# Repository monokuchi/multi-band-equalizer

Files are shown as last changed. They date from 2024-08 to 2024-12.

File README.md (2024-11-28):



<!-- PROJECT LOGO -->
<div align="center">
  <h1>Multi-Band Equalizer</h1>
  <p>
    Multi-band parametric equalizer implemented using a STM32H7 ARM7 Microcontroller along with a Cirrus Logic CS4272-CZZ Audio Codec
  </p>
</div>

<!-- PROJECT DESCRIPTION -->
<h2>Description</h2> 

<header>
    <ul>
        <li><h3>Multi-Band-Equalizer Front Side</h3></li>
    </ul>
</header>

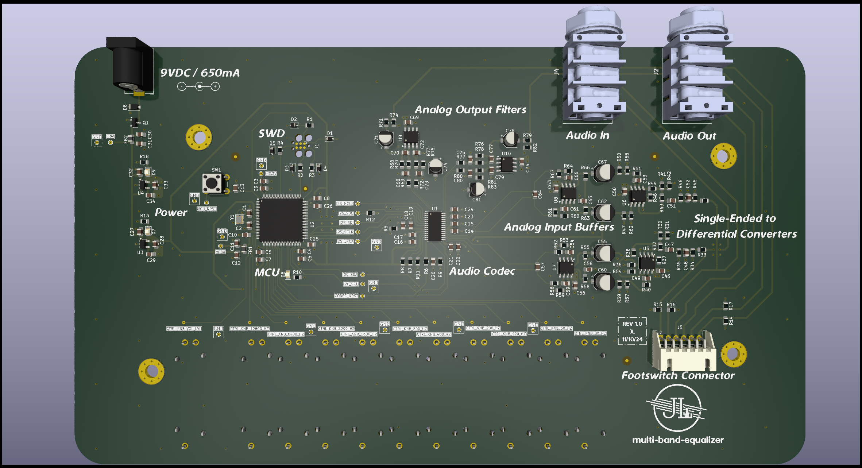
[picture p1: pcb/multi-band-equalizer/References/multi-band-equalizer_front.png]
Multi-Band-Equalizer PCB Front Side


<header>
    <ul>
        <li><h3>Multi-Band-Equalizer Back Side</h3></li>
    </ul>
</header>

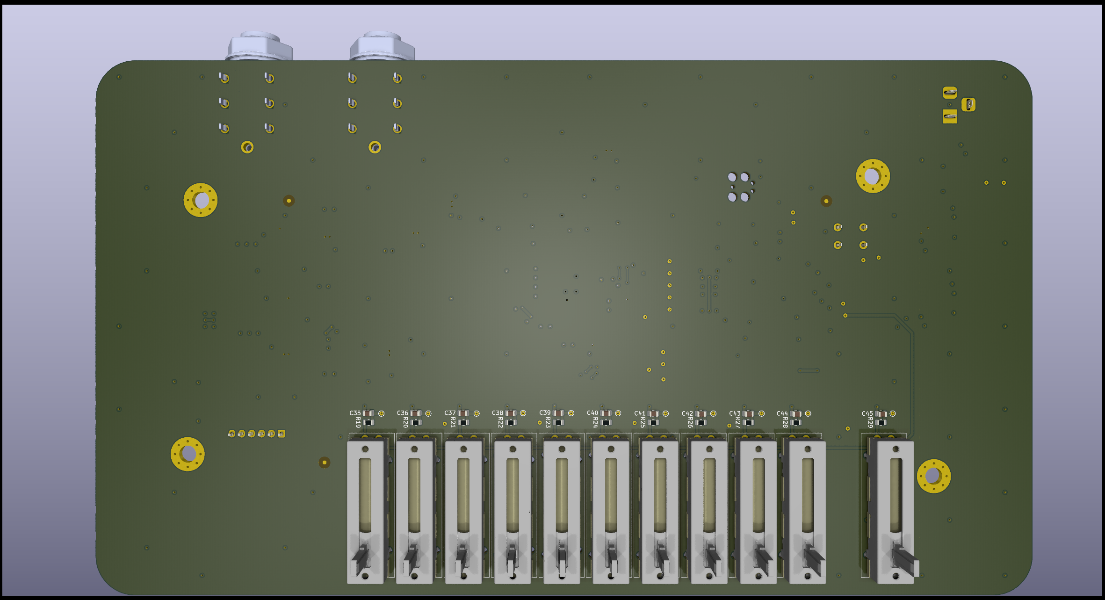
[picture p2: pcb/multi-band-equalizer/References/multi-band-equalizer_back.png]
Multi-Band-Equalizer PCB Back Side


<header>
    <ul>
        <li><h3>CS4272-CZZ Breakout Board</h3></li>
    </ul>
</header>

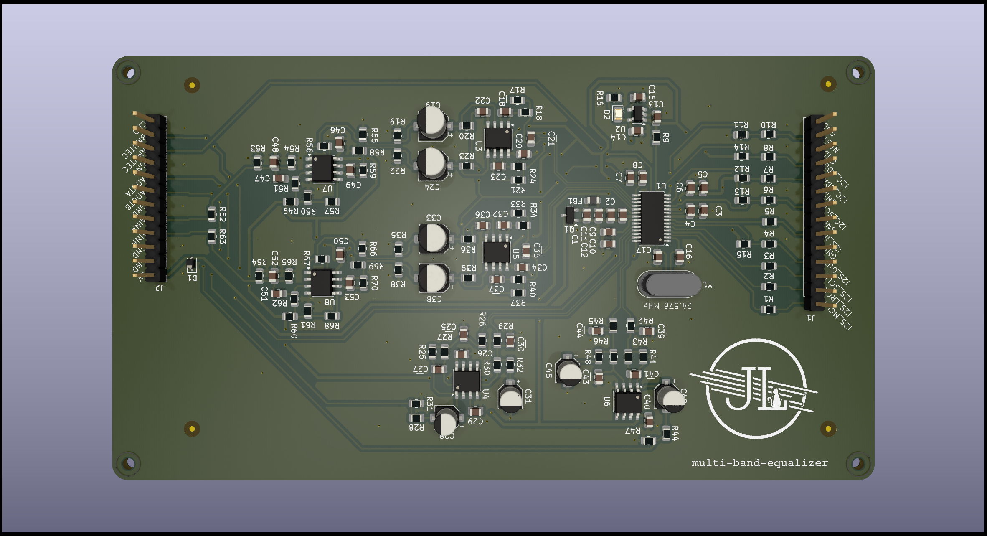
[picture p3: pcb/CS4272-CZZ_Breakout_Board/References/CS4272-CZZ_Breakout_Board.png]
CS4272-CZZ_Breakout_Board PCB Front Side


10-band parametric equalizer using digital 2 stage IIR peaking filters.

Features:
* Efficent pipelining of stereo audio samples to/from the MCU and the codec by utilizing double buffering as well as DMA streams
* Fast computation of cascaded IIR filter stages by taking advantage of ARM's CMSIS DSP libaries (Decreases compute time by ~64%!)
* Generic design of hardware allows for this PCB to used for more then an EQ. All you need to do is change the firmware to alter the processing of the audio samples

Check out this *[script][python-script-url]* for simulating the cascaded filter responses

<p align="right">(<a href="#readme-top">back to top</a>)</p>

<!-- MARKDOWN LINKS & IMAGES -->
[multi-band-equalizer-pcb-front]: pcb/multi-band-equalizer/References/multi-band-equalizer_front.png
[multi-band-equalizer-pcb-back]: pcb/multi-band-equalizer/References/multi-band-equalizer_back.png
[cs4272-czz_breakout_board-front]: pcb/CS4272-CZZ_Breakout_Board/References/CS4272-CZZ_Breakout_Board.png
[python-script-url]: scripts/peaking_filter.py

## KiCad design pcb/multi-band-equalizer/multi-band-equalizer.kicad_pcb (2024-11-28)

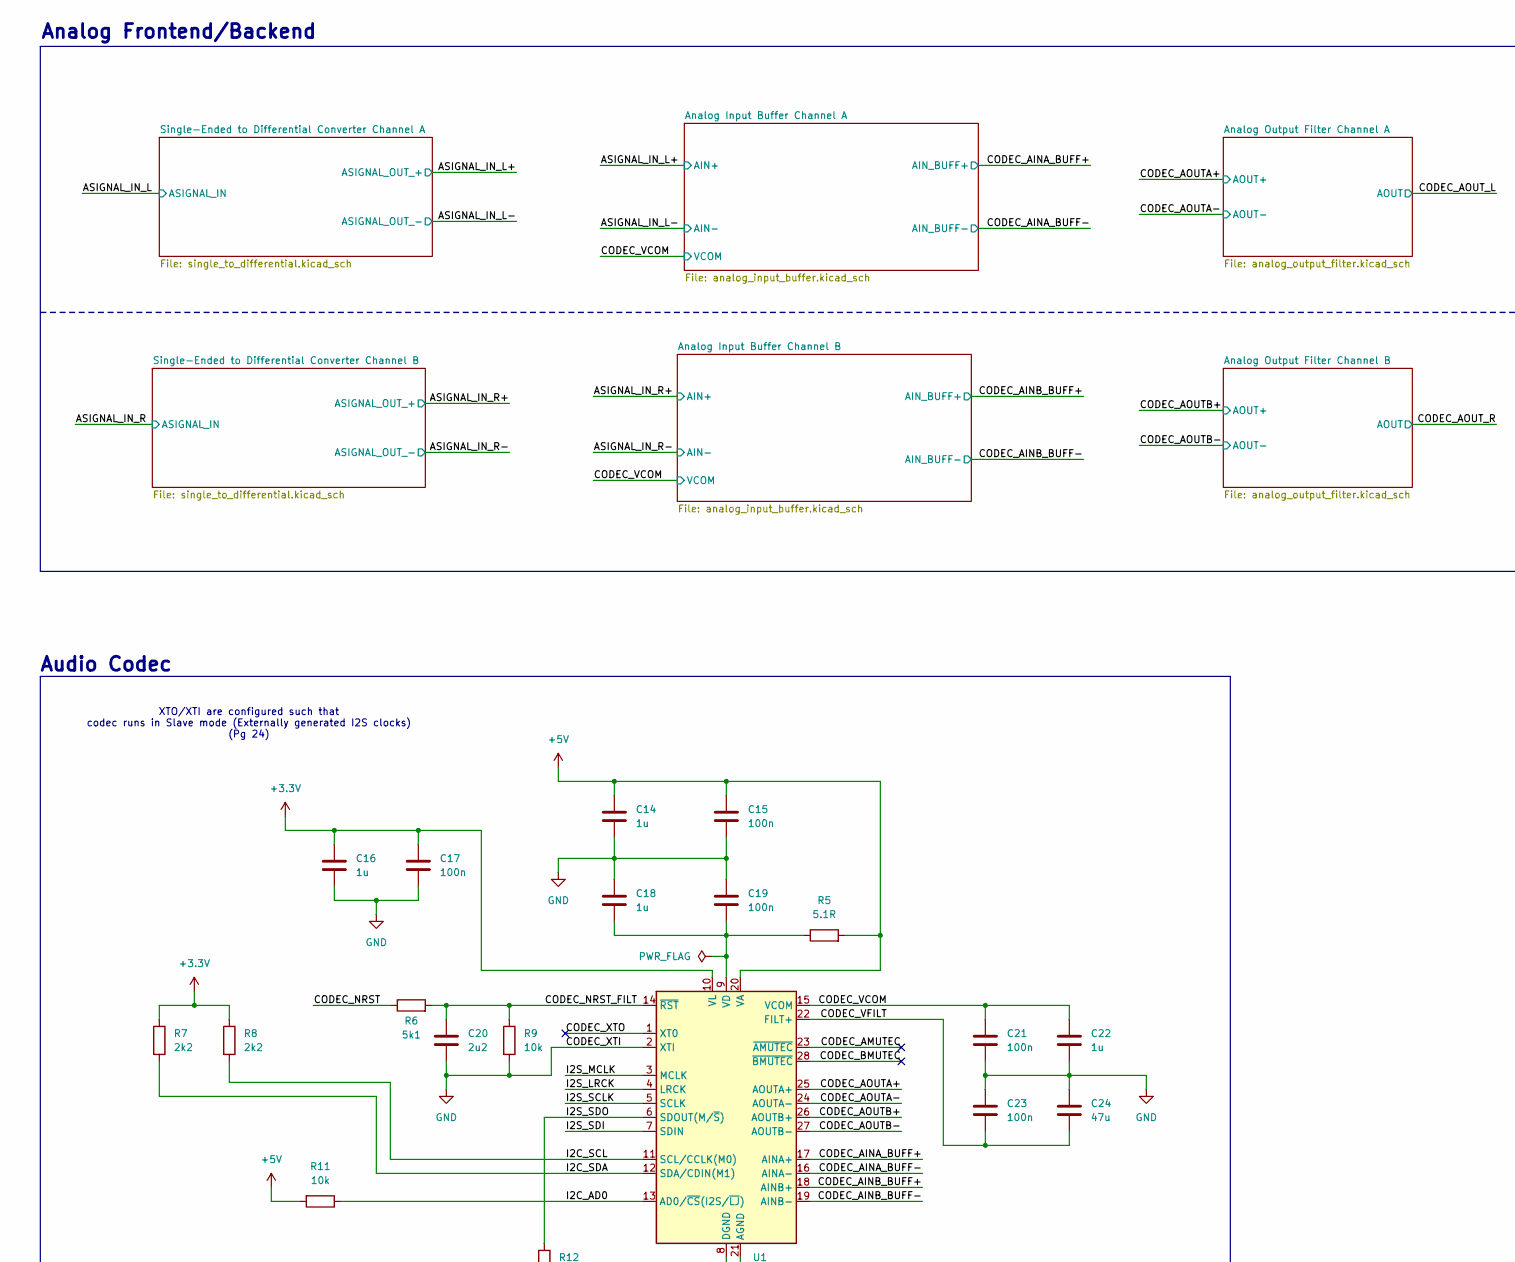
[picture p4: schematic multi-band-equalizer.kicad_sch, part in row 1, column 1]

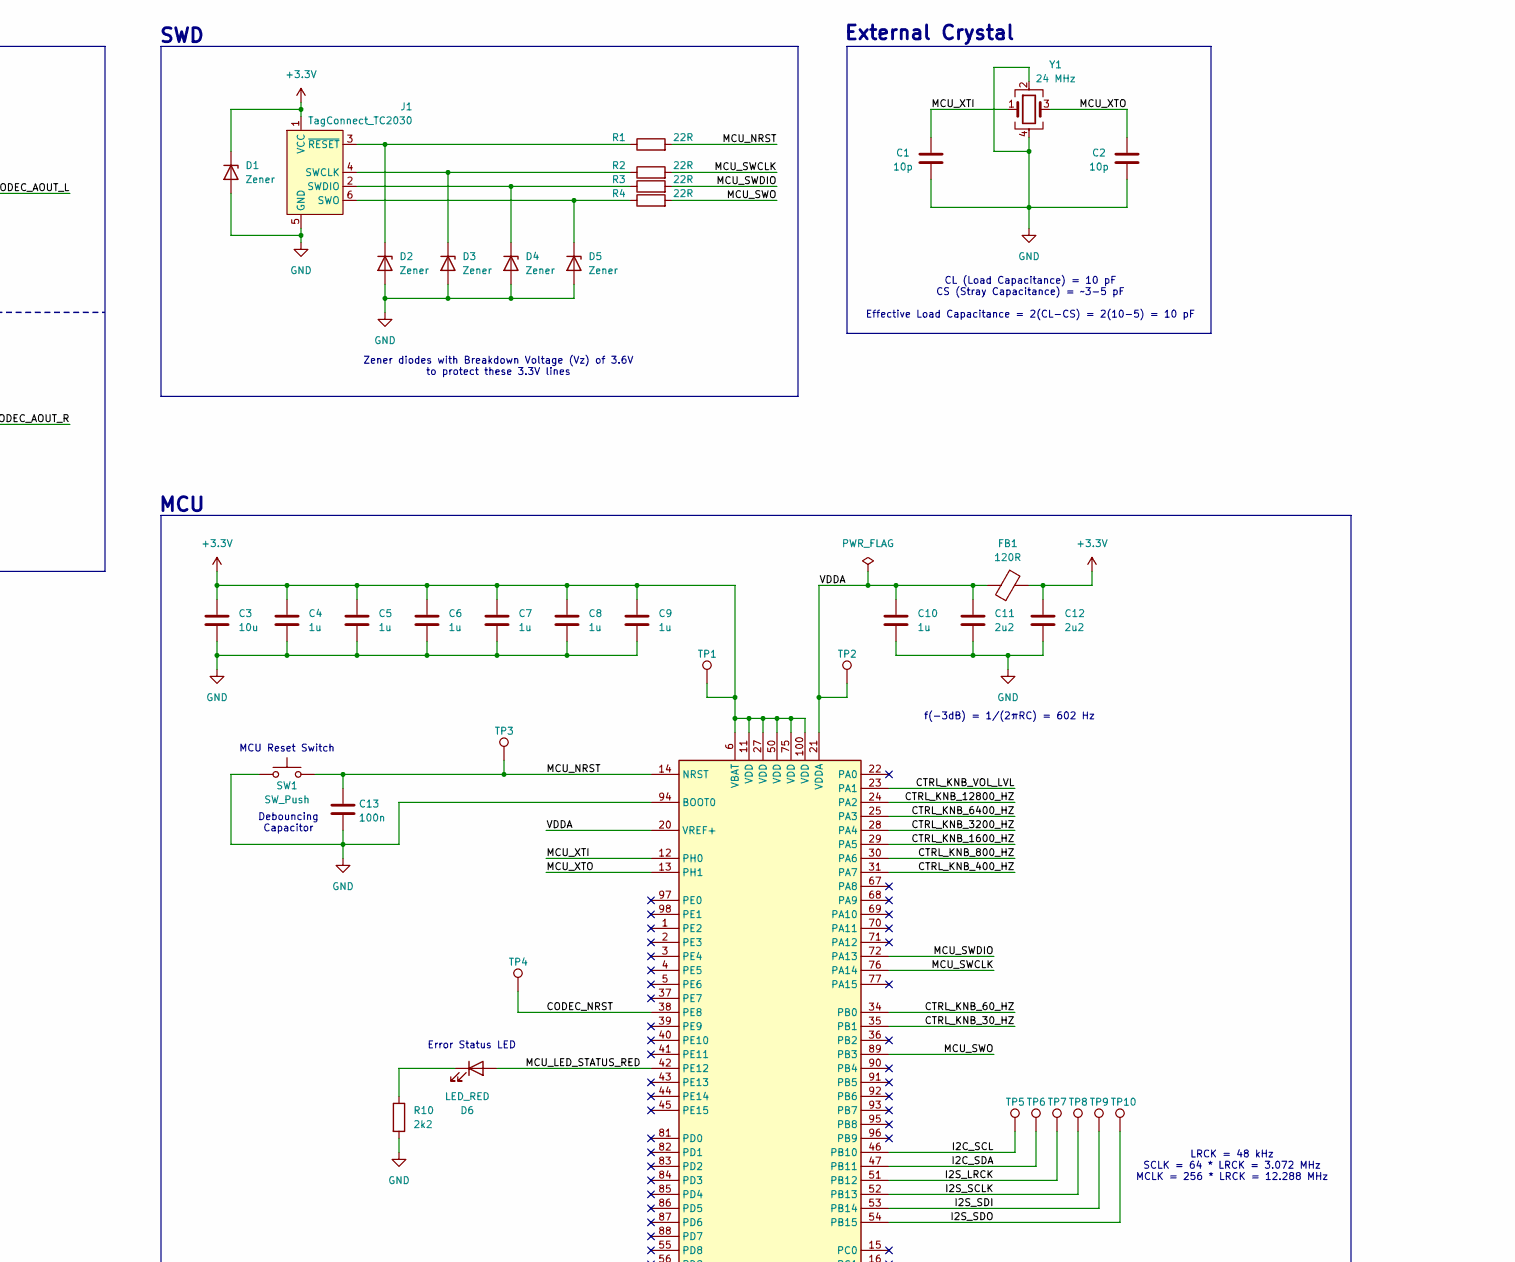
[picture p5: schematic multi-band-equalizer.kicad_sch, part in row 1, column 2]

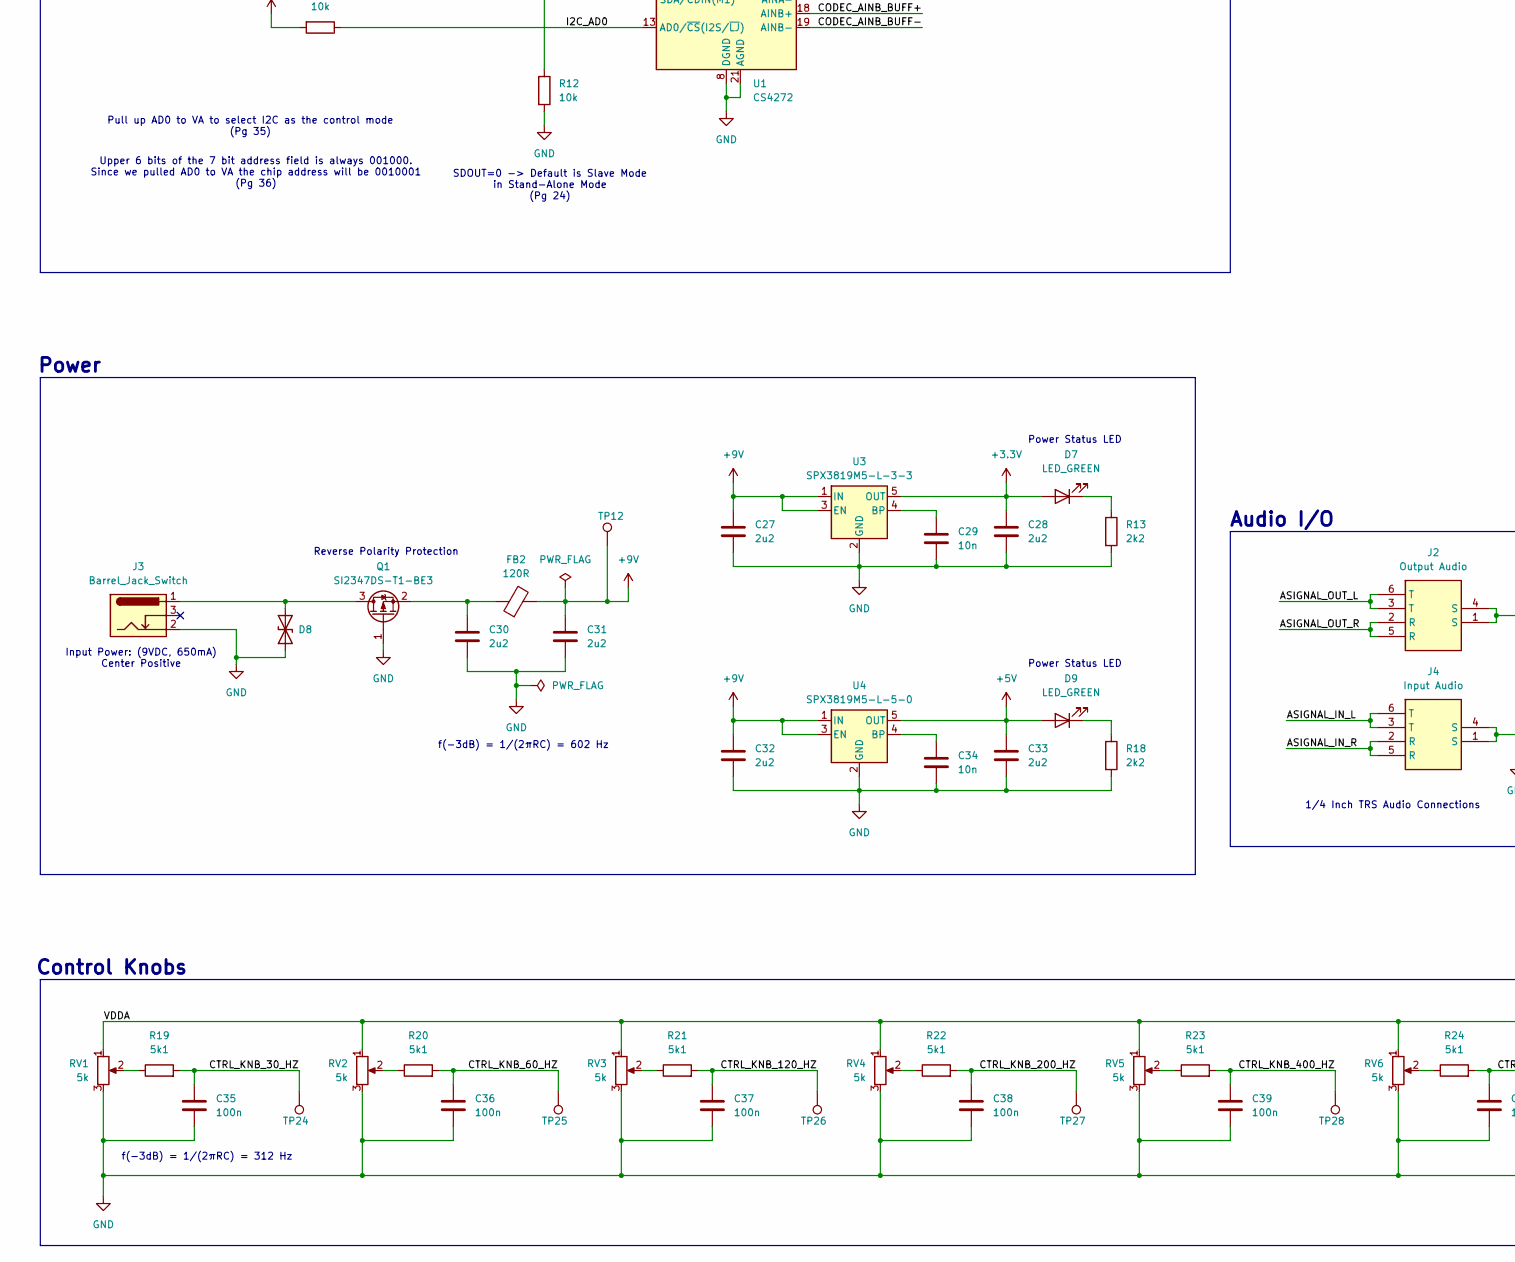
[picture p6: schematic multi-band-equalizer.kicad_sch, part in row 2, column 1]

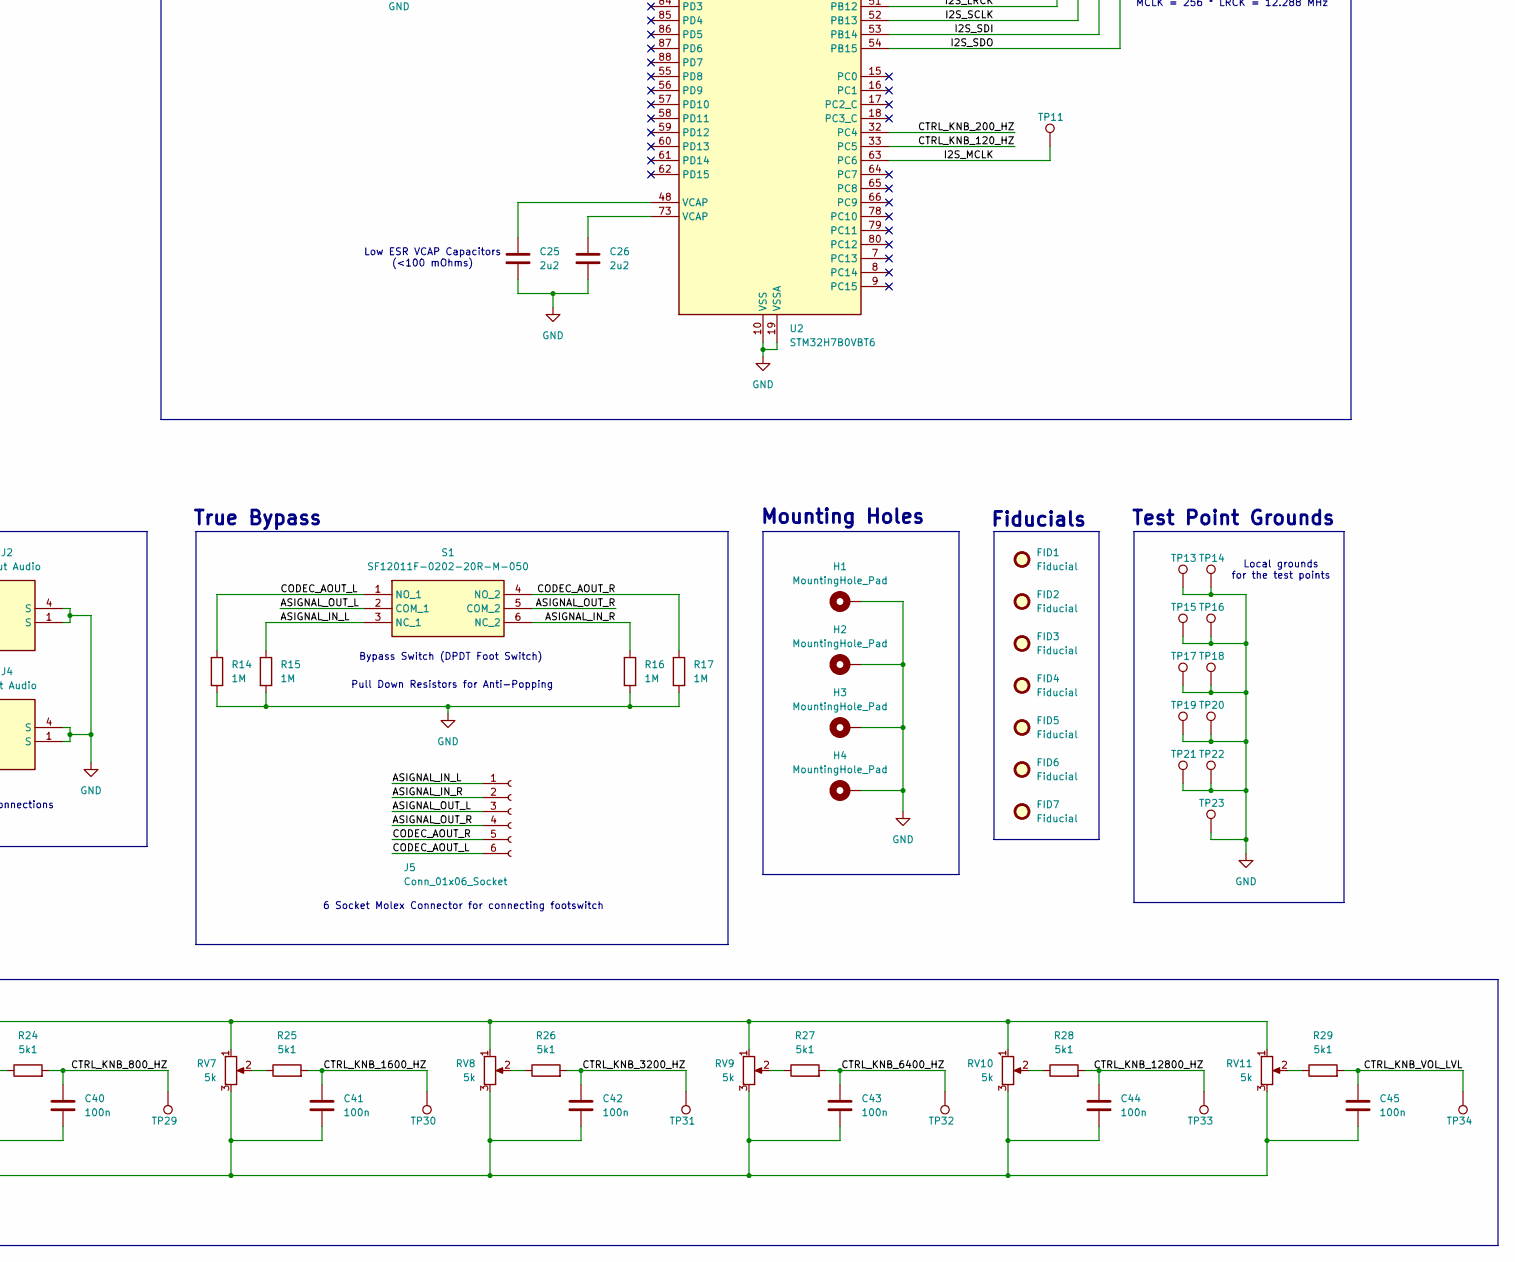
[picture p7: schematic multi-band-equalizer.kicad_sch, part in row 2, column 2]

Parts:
C1, C2: 10p; C_0805_2012Metric
C3: 10u; C_0805_2012Metric
C4, C5, C6, C7, C8, C9, C10, C14, C16, C18, C22: 1u; C_0805_2012Metric
C11, C12, C20, C25, C26, C27, C28, C30, C31, C32, C33: 2u2; C_0805_2012Metric
C13, C15, C17, C19, C21, C23, C35, C36, C37, C38, C39, C40, C41, C42, C43, C44, C45: 100n; C_0805_2012Metric
C24: 47u; C_0805_2012Metric
C29, C34: 10n; C_0805_2012Metric
D1, D2, D3, D4, D5: Zener; D_SOD-323
D6: LED_RED; LED_0805_2012Metric
D7, D9: LED_GREEN; LED_0805_2012Metric
D8: D_TVS; D_SOD-123F
FB1, FB2: 120R; L_0805_2012Metric
FID1, FID2, FID3, FID4, FID5, FID6: Fiducial; Fiducial_1mm_Mask3mm
FID7: Fiducial; Fiducial_1mm_Mask2mm
H1, H2, H3, H4: MountingHole_Pad; MountingHole_4.3mm_M4_Pad_Via
J1: TagConnect_TC2030; Tag-Connect_TC2030-IDC-FP_2x03_P1.27mm_Vertical
J2: Output Audio; ACJSMHDR; Manufacturer_Part_Number ACJS-MHDR; Mouser Part Number 523-ACJS-MHDR
J3: Barrel_Jack_Switch; BarrelJack_Horizontal
J4: Input Audio; ACJSMHDR; Manufacturer_Part_Number ACJS-MHDR; Mouser Part Number 523-ACJS-MHDR
J5: Conn_01x06_Socket; JST_XH_S6B-XH-A_1x06_P2.50mm_Horizontal
Q1: SI2347DS-T1-BE3; SOT-23-3
R1, R2, R3, R4: 22R; R_0805_2012Metric
R5: 5.1R; R_0805_2012Metric
R6, R19, R20, R21, R22, R23, R24, R25, R26, R27, R28, R29: 5k1; R_0805_2012Metric
R7, R8, R10, R13, R18: 2k2; R_0805_2012Metric
R9, R11, R12: 10k; R_0805_2012Metric
R14, R15, R16, R17: 1M; R_0805_2012Metric
RV1, RV2, RV3, RV4, RV5, RV6, RV7, RV8, RV9, RV10, RV11: 5k; PTA2043-2015CPB502
S1: SF12011F-0202-20R-M-050; SF12011F020220RM050; Manufacturer_Part_Number SF12011F-0202-20R-M-050; Mouser Part Number 107-SF12011F-M
SW1: SW_Push; SW_PUSH_6mm_H4.3mm
TP1, TP2, TP3, TP4, TP5, TP6, TP7, TP8, TP9, TP10, TP11, TP12, TP13, TP14, TP15, TP16, TP17, TP18, TP19, TP20, TP21, TP22, TP23, TP24, TP25, TP26, TP27, TP28, TP29, TP30, TP31, TP32, TP33, TP34: TestPoint; TestPoint_THTPad_D1.0mm_Drill0.5mm
U1: CS4272; TSSOP-28_4.4x9.7mm_P0.65mm
U2: STM32H7B0VBT6; LQFP-100_14x14mm_P0.5mm
U3: SPX3819M5-L-3-3; SOT-23-5
U4: SPX3819M5-L-5-0; SOT-23-5
Y1: 24 MHz; Crystal_SMD_2520-4Pin_2.5x2.0mm

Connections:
+3.3V: C3.1, C4.1, C5.1, C6.1, C7.1, C8.1, C9.1, C12.1, C16.1, C17.1, C28.1, D1.1 (K), D7.2 (A), FB1.2, J1.1 (VCC), R7.1, R8.1, TP1.1, U1.10 (VL), U2.6 (VBAT), U2.11 (VDD), U2.27 (VDD), U2.50 (VDD), U2.75 (VDD), U2.100 (VDD), U3.5 (OUT)
+5V: C14.1, C15.1, C33.1, D9.2 (A), R5.2, R11.2, U1.20 (VA), U4.5 (OUT); also elsewhere on the board
+9V: C27.1, C31.1, C32.1, FB2.2, TP12.1, U3.1 (IN), U3.3 (EN), U4.1 (IN), U4.3 (EN)
/ASIGNAL_IN_L: J4.3 (T), J4.6 (T), J5.1, R15.1, S1.3 (NC_1); also elsewhere on the board
/ASIGNAL_IN_R: J4.2 (R), J4.5 (R), J5.2, R16.1, S1.6 (NC_2); also elsewhere on the board
/ASIGNAL_OUT_L: J2.3 (T), J2.6 (T), J5.3, S1.2 (COM_1)
/ASIGNAL_OUT_R: J2.2 (R), J2.5 (R), J5.4, S1.5 (COM_2)
/CODEC_AINA_BUFF+: U1.17 (AINA+); also elsewhere on the board
/CODEC_AINA_BUFF-: U1.16 (AINA-); also elsewhere on the board
/CODEC_AINB_BUFF+: U1.18 (AINB+); also elsewhere on the board
/CODEC_AINB_BUFF-: U1.19 (AINB-); also elsewhere on the board
/CODEC_AMUTEC: U1.23 (~AMUTEC)
/CODEC_AOUTA+: U1.25 (AOUTA+); also elsewhere on the board
/CODEC_AOUTA-: U1.24 (AOUTA-); also elsewhere on the board
/CODEC_AOUTB+: U1.26 (AOUTB+); also elsewhere on the board
/CODEC_AOUTB-: U1.27 (AOUTB-); also elsewhere on the board
/CODEC_AOUT_L: J5.6, R14.1, S1.1 (NO_1); also elsewhere on the board
/CODEC_AOUT_R: J5.5, R17.1, S1.4 (NO_2); also elsewhere on the board
/CODEC_BMUTEC: U1.28 (~BMUTEC)
/CODEC_NRST: R6.1, TP4.1, U2.38 (PE8)
/CODEC_NRST_FILT: C20.1, R6.2, R9.1, U1.14 (~RST)
/CODEC_VCOM: C21.1, C22.1, U1.15 (VCOM); also elsewhere on the board
/CODEC_VFILT: C23.2, C24.2, U1.22 (FILT+)
/CODEC_XTO: U1.1 (XT0)
/CTRL_KNB_30_HZ: C35.1, R19.2, TP24.1, U2.35 (PB1)
/CTRL_KNB_60_HZ: C36.1, R20.2, TP25.1, U2.34 (PB0)
/CTRL_KNB_120_HZ: C37.1, R21.2, TP26.1, U2.33 (PC5)
/CTRL_KNB_200_HZ: C38.1, R22.2, TP27.1, U2.32 (PC4)
/CTRL_KNB_400_HZ: C39.1, R23.2, TP28.1, U2.31 (PA7)
/CTRL_KNB_800_HZ: C40.1, R24.2, TP29.1, U2.30 (PA6)
/CTRL_KNB_1600_HZ: C41.1, R25.2, TP30.1, U2.29 (PA5)
/CTRL_KNB_3200_HZ: C42.1, R26.2, TP31.1, U2.28 (PA4)
/CTRL_KNB_6400_HZ: C43.1, R27.2, TP32.1, U2.25 (PA3)
/CTRL_KNB_12800_HZ: C44.1, R28.2, TP33.1, U2.24 (PA2)
/CTRL_KNB_VOL_LVL: C45.1, R29.2, TP34.1, U2.23 (PA1)
/I2C_AD0: R11.1, U1.13 (AD0/~CS(I2S/~LJ))
/I2C_SCL: R8.2, TP5.1, U1.11 (SCL/CCLK(M0)), U2.46 (PB10)
/I2C_SDA: R7.2, TP6.1, U1.12 (SDA/CDIN(M1)), U2.47 (PB11)
/I2S_LRCK: TP7.1, U1.4 (LRCK), U2.51 (PB12)
/I2S_MCLK: TP11.1, U1.3 (MCLK), U2.63 (PC6)
/I2S_SCLK: TP8.1, U1.5 (SCLK), U2.52 (PB13)
/I2S_SDI: TP9.1, U1.7 (SDIN), U2.53 (PB14)
/I2S_SDO: R12.1, TP10.1, U1.6 (SDOUT(M/~S)), U2.54 (PB15)
/MCU_LED_STATUS_RED: D6.2 (A), U2.42 (PE12)
/MCU_NRST: C13.1, R1.2, SW1.2, TP3.1, U2.14 (NRST)
/MCU_SWCLK: R2.2, U2.76 (PA14)
/MCU_SWDIO: R3.2, U2.72 (PA13)
/MCU_SWO: R4.2, U2.89 (PB3)
/MCU_XTI: C1.1, U2.12 (PH0), Y1.1
/MCU_XTO: C2.1, U2.13 (PH1), Y1.3
/VDDA: C10.1, C11.1, FB1.1, RV1.1, RV2.1, RV3.1, RV4.1, RV5.1, RV6.1, RV7.1, RV8.1, RV9.1, RV10.1, RV11.1, TP2.1, U2.20 (VREF+), U2.21 (VDDA)
GND: C1.2, C2.2, C3.2, C4.2, C5.2, C6.2, C7.2, C8.2, C9.2, C10.2, C11.2, C12.2, C13.2, C14.2, C15.2, C16.2, C17.2, C18.1, C19.1, C20.2, C21.2, C22.2, C23.1, C24.1, C25.2, C26.2, C27.2, C28.2, C29.2, C30.2, C31.2, C32.2, C33.2, C34.2, C35.2, C36.2, C37.2, C38.2, C39.2, C40.2, C41.2, C42.2, C43.2, C44.2, C45.2, D1.2 (A), D2.2 (A), D3.2 (A), D4.2 (A), D5.2 (A), D8.1 (A1), H1.1, H2.1, H3.1, H4.1, J1.5 (GND), J2.1 (S), J2.4 (S), J3.2, J4.1 (S), J4.4 (S), Q1.1 (G), R9.2, R10.2, R12.2, R13.2, R14.2, R15.2, R16.2, R17.2, R18.2, RV1.3, RV2.3, RV3.3, RV4.3, RV5.3, RV6.3, RV7.3, RV8.3, RV9.3, RV10.3, RV11.3, SW1.1, TP13.1, TP14.1, TP15.1, TP16.1, TP17.1, TP18.1, TP19.1, TP20.1, TP21.1, TP22.1, TP23.1, U1.2 (XTI), U1.8 (DGND), U1.21 (AGND), U2.10 (VSS), U2.19 (VSSA), U2.26 (VSS), U2.49 (VSS), U2.74 (VSS), U2.94 (BOOT0), U2.99 (VSS), U3.2 (GND), U4.2 (GND), Y1.2, Y1.4; also elsewhere on the board
unnamed: C25.1, U2.48 (VCAP)
unnamed: C26.1, U2.73 (VCAP)
unnamed: D2.1 (K), J1.3 (~RESET), R1.1
unnamed: D3.1 (K), J1.4 (SWCLK), R2.1
unnamed: D4.1 (K), J1.2 (SWDIO), R3.1
unnamed: D5.1 (K), J1.6 (SWO), R4.1
unnamed: D6.1 (K), R10.1
unnamed: D7.1 (K), R13.1
unnamed: D8.2 (A2), J3.1, Q1.3 (D)
unnamed: D9.1 (K), R18.1
unnamed: C30.1, FB2.1, Q1.2 (S)
unnamed: R19.1, RV1.2
unnamed: R20.1, RV2.2
unnamed: R21.1, RV3.2
unnamed: R22.1, RV4.2
unnamed: R23.1, RV5.2
unnamed: R24.1, RV6.2
unnamed: R25.1, RV7.2
unnamed: R26.1, RV8.2
unnamed: R27.1, RV9.2
unnamed: R28.1, RV10.2
unnamed: R29.1, RV11.2
unnamed: C18.2, C19.2, R5.1, U1.9 (VD)
unnamed: C29.1, U3.4 (BP)
unnamed: C34.1, U4.4 (BP)

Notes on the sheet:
Power Status LED
Test Point Grounds
1/4 Inch TRS Audio Connections
Debouncing Capacitor
Bypass Switch (DPDT Foot Switch)
Reverse Polarity Protection
Audio I/O
Error Status LED
Upper 6 bits of the 7 bit address field is always 001000. Since we pulled AD0 to VA the chip address will be 0010001 (Pg 36)
XTO/XTI are configured such that codec runs in Slave mode (Externally generated I2S clocks) (Pg 24)
f(-3dB) = 1/(2πRC) = 602 Hz
MCU
f(-3dB) = 1/(2πRC) = 312 Hz
SWD
LRCK = 48 kHz SCLK = 64 * LRCK = 3.072 MHz MCLK = 256 * LRCK = 12.288 MHz
6 Socket Molex Connector for connecting footswitch
Audio Codec
Local grounds for the test points
Low ESR VCAP Capacitors (<100 mOhms)
Zener diodes with Breakdown Voltage (Vz) of 3.6V to protect these 3.3V lines
SDOUT=0 -> Default is Slave Mode in Stand-Alone Mode (Pg 24)
Fiducials
True Bypass
External Crystal
CL (Load Capacitance) = 10 pF CS (Stray Capacitance) = ~3-5 pF Effective Load Capacitance = 2(CL-CS) = 2(10-5) = 10 pF
Power
Pull Down Resistors for Anti-Popping
Analog Frontend/Backend
Control Knobs
Input Power: (9VDC, 650mA) Center Positive
Mounting Holes
MCU Reset Switch
Pull up AD0 to VA to select I2C as the control mode (Pg 35)

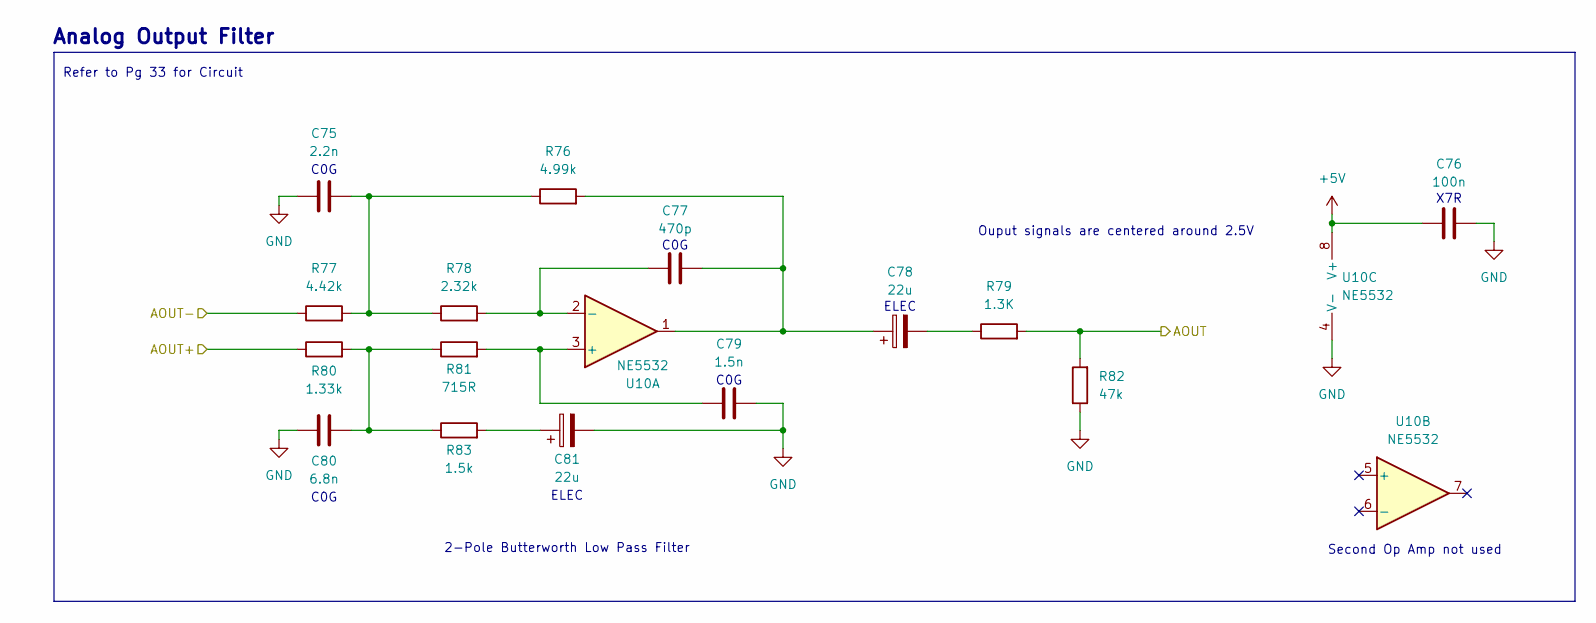
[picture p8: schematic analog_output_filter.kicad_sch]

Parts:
C75: 2.2n; C_0805_2012Metric
C76: 100n; C_0805_2012Metric
C77: 470p; C_0805_2012Metric
C78, C81: 22u; CP_Elec_4x5.4
C79: 1.5n; C_0805_2012Metric
C80: 6.8n; C_0805_2012Metric
R76: 4.99k; R_0805_2012Metric
R77: 4.42k; R_0805_2012Metric
R78: 2.32k; R_0805_2012Metric
R79: 1.3K; R_0805_2012Metric
R80: 1.33k; R_0805_2012Metric
R81: 715R; R_0805_2012Metric
R82: 47k; R_0805_2012Metric
R83: 1.5k; R_0805_2012Metric
U10: NE5532; SOIC-8_3.9x4.9mm_P1.27mm

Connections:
+5V: C76.1, U10.8 (V+); also elsewhere on the board
/CODEC_AOUTB+: R80.1; also elsewhere on the board
/CODEC_AOUTB-: R77.1; also elsewhere on the board
/CODEC_AOUT_R: R79.2, R82.2; also elsewhere on the board
GND: C75.1, C76.2, C79.2, C80.1, C81.2, R82.1, U10.4 (V-); also elsewhere on the board
unnamed: C75.2, R76.1, R77.2, R78.1
unnamed: C77.2, C78.1, R76.2, U10.1
unnamed: C78.2, R79.1
unnamed: C80.2, R80.2, R81.1, R83.1
unnamed: C81.1, R83.2
unnamed: C79.1, R81.2, U10.3 (+)
unnamed: C77.1, R78.2, U10.2 (-)

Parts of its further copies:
C68: 2.2n; C_0805_2012Metric
C69: 100n; C_0805_2012Metric
C70: 470p; C_0805_2012Metric
C71, C74: 22u; CP_Elec_4x5.4
C72: 1.5n; C_0805_2012Metric
C73: 6.8n; C_0805_2012Metric
R68: 4.99k; R_0805_2012Metric
R69: 4.42k; R_0805_2012Metric
R70: 2.32k; R_0805_2012Metric
R71: 1.3K; R_0805_2012Metric
R72: 1.33k; R_0805_2012Metric
R73: 715R; R_0805_2012Metric
R74: 47k; R_0805_2012Metric
R75: 1.5k; R_0805_2012Metric
U9: NE5532; SOIC-8_3.9x4.9mm_P1.27mm

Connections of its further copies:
+5V: C69.1, U9.8 (V+); also elsewhere on the board
/CODEC_AOUTA+: R72.1; also elsewhere on the board
/CODEC_AOUTA-: R69.1; also elsewhere on the board
/CODEC_AOUT_L: R71.2, R74.2; also elsewhere on the board
GND: C68.1, C69.2, C72.2, C73.1, C74.2, R74.1, U9.4 (V-); also elsewhere on the board
unnamed: C68.2, R68.1, R69.2, R70.1
unnamed: C70.2, C71.1, R68.2, U9.1
unnamed: C71.2, R71.1
unnamed: C73.2, R72.2, R73.1, R75.1
unnamed: C74.1, R75.2
unnamed: C72.1, R73.2, U9.3 (+)
unnamed: C70.1, R70.2, U9.2 (-)

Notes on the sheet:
C0G
Refer to Pg 33 for Circuit
X7R
2-Pole Butterworth Low Pass Filter
Second Op Amp not used
Ouput signals are centered around 2.5V
ELEC
Analog Output Filter

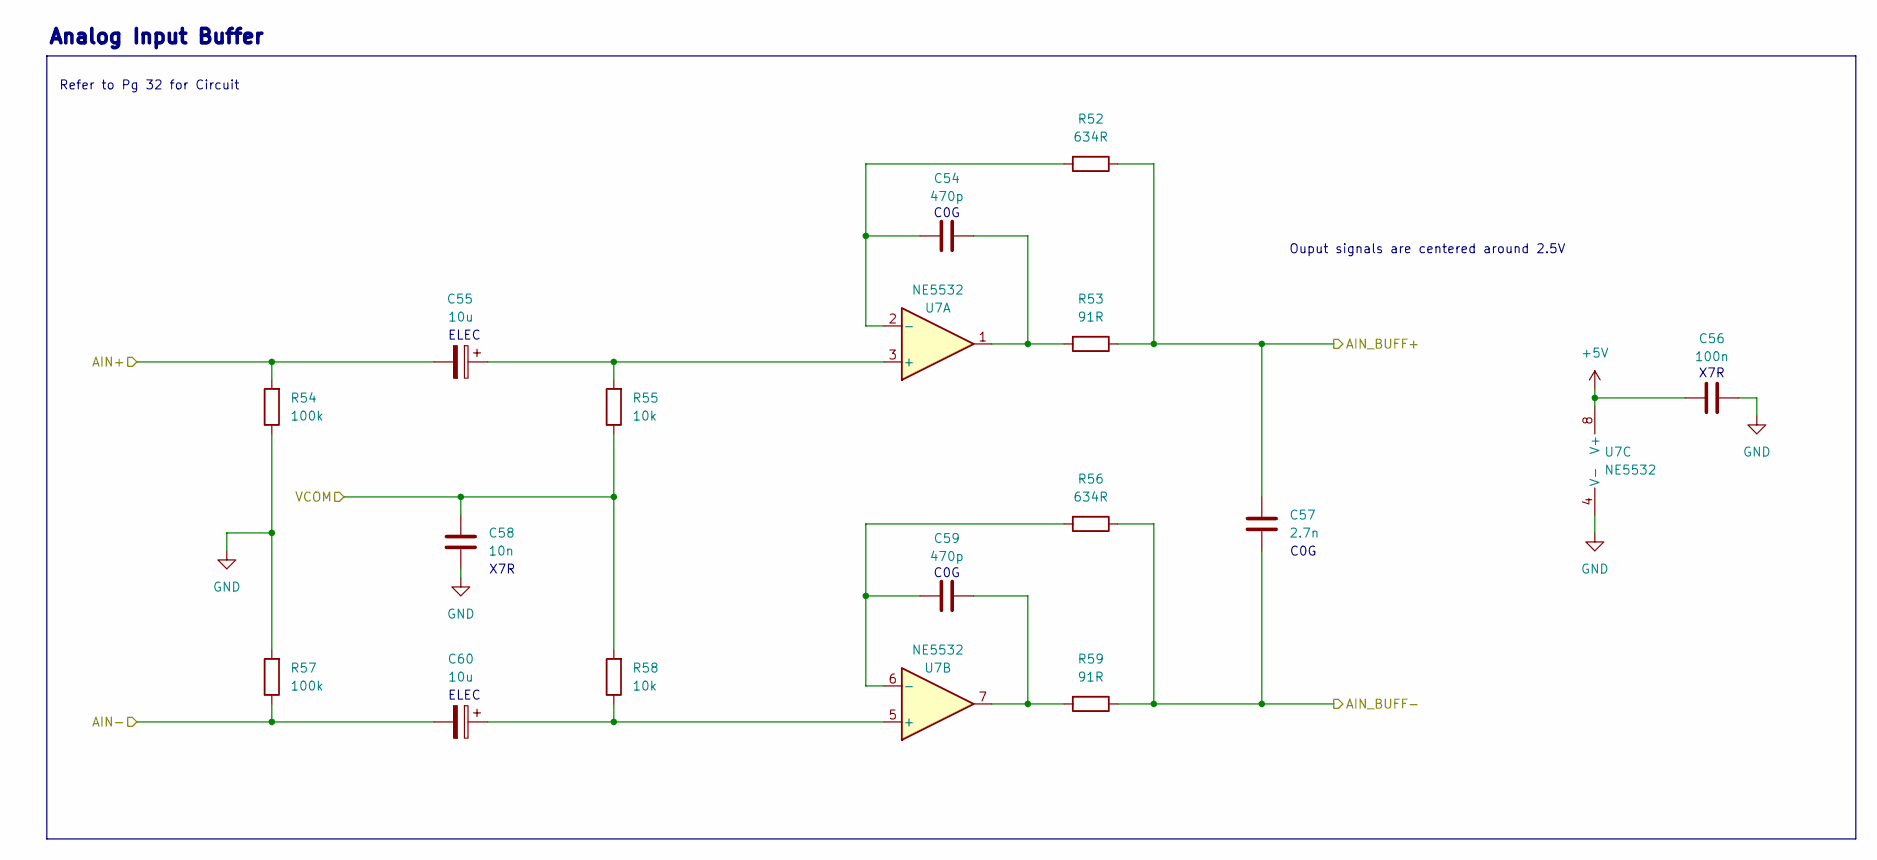
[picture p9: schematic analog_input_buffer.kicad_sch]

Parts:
C54, C59: 470p; C_0805_2012Metric
C55, C60: 10u; CP_Elec_5x5.4
C56: 100n; C_0805_2012Metric
C57: 2.7n; C_0805_2012Metric
C58: 10n; C_0805_2012Metric
R52, R56: 634R; R_0805_2012Metric
R53, R59: 91R; R_0805_2012Metric
R54, R57: 100k; R_0805_2012Metric
R55, R58: 10k; R_0805_2012Metric
U7: NE5532; SOIC-8_3.9x4.9mm_P1.27mm

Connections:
+5V: C56.1, U7.8 (V+); also elsewhere on the board
/ASIGNAL_IN_L+: C55.2, R54.2; also elsewhere on the board
/ASIGNAL_IN_L-: C60.2, R57.1; also elsewhere on the board
/CODEC_AINA_BUFF+: C57.2, R52.1, R53.1; also elsewhere on the board
/CODEC_AINA_BUFF-: C57.1, R56.1, R59.1; also elsewhere on the board
/CODEC_VCOM: C58.1, R55.1, R58.2; also elsewhere on the board
GND: C56.2, C58.2, R54.1, R57.2, U7.4 (V-); also elsewhere on the board
unnamed: C54.2, R53.2, U7.1
unnamed: C59.2, R59.2, U7.7
unnamed: C55.1, R55.2, U7.3 (+)
unnamed: C54.1, R52.2, U7.2 (-)
unnamed: C60.1, R58.1, U7.5 (+)
unnamed: C59.1, R56.2, U7.6 (-)

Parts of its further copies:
C61, C66: 470p; C_0805_2012Metric
C62, C67: 10u; CP_Elec_5x5.4
C63: 100n; C_0805_2012Metric
C64: 2.7n; C_0805_2012Metric
C65: 10n; C_0805_2012Metric
R60, R64: 634R; R_0805_2012Metric
R61, R67: 91R; R_0805_2012Metric
R62, R65: 100k; R_0805_2012Metric
R63, R66: 10k; R_0805_2012Metric
U8: NE5532; SOIC-8_3.9x4.9mm_P1.27mm

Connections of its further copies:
+5V: C63.1, U8.8 (V+); also elsewhere on the board
/ASIGNAL_IN_R+: C62.2, R62.2; also elsewhere on the board
/ASIGNAL_IN_R-: C67.2, R65.1; also elsewhere on the board
/CODEC_AINB_BUFF+: C64.2, R60.1, R61.1; also elsewhere on the board
/CODEC_AINB_BUFF-: C64.1, R64.1, R67.1; also elsewhere on the board
/CODEC_VCOM: C65.1, R63.1, R66.2; also elsewhere on the board
GND: C63.2, C65.2, R62.1, R65.2, U8.4 (V-); also elsewhere on the board
unnamed: C61.2, R61.2, U8.1
unnamed: C66.2, R67.2, U8.7
unnamed: C62.1, R63.2, U8.3 (+)
unnamed: C61.1, R60.2, U8.2 (-)
unnamed: C67.1, R66.1, U8.5 (+)
unnamed: C66.1, R64.2, U8.6 (-)

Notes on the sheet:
C0G
Analog Input Buffer
X7R
Refer to Pg 32 for Circuit
Ouput signals are centered around 2.5V
ELEC

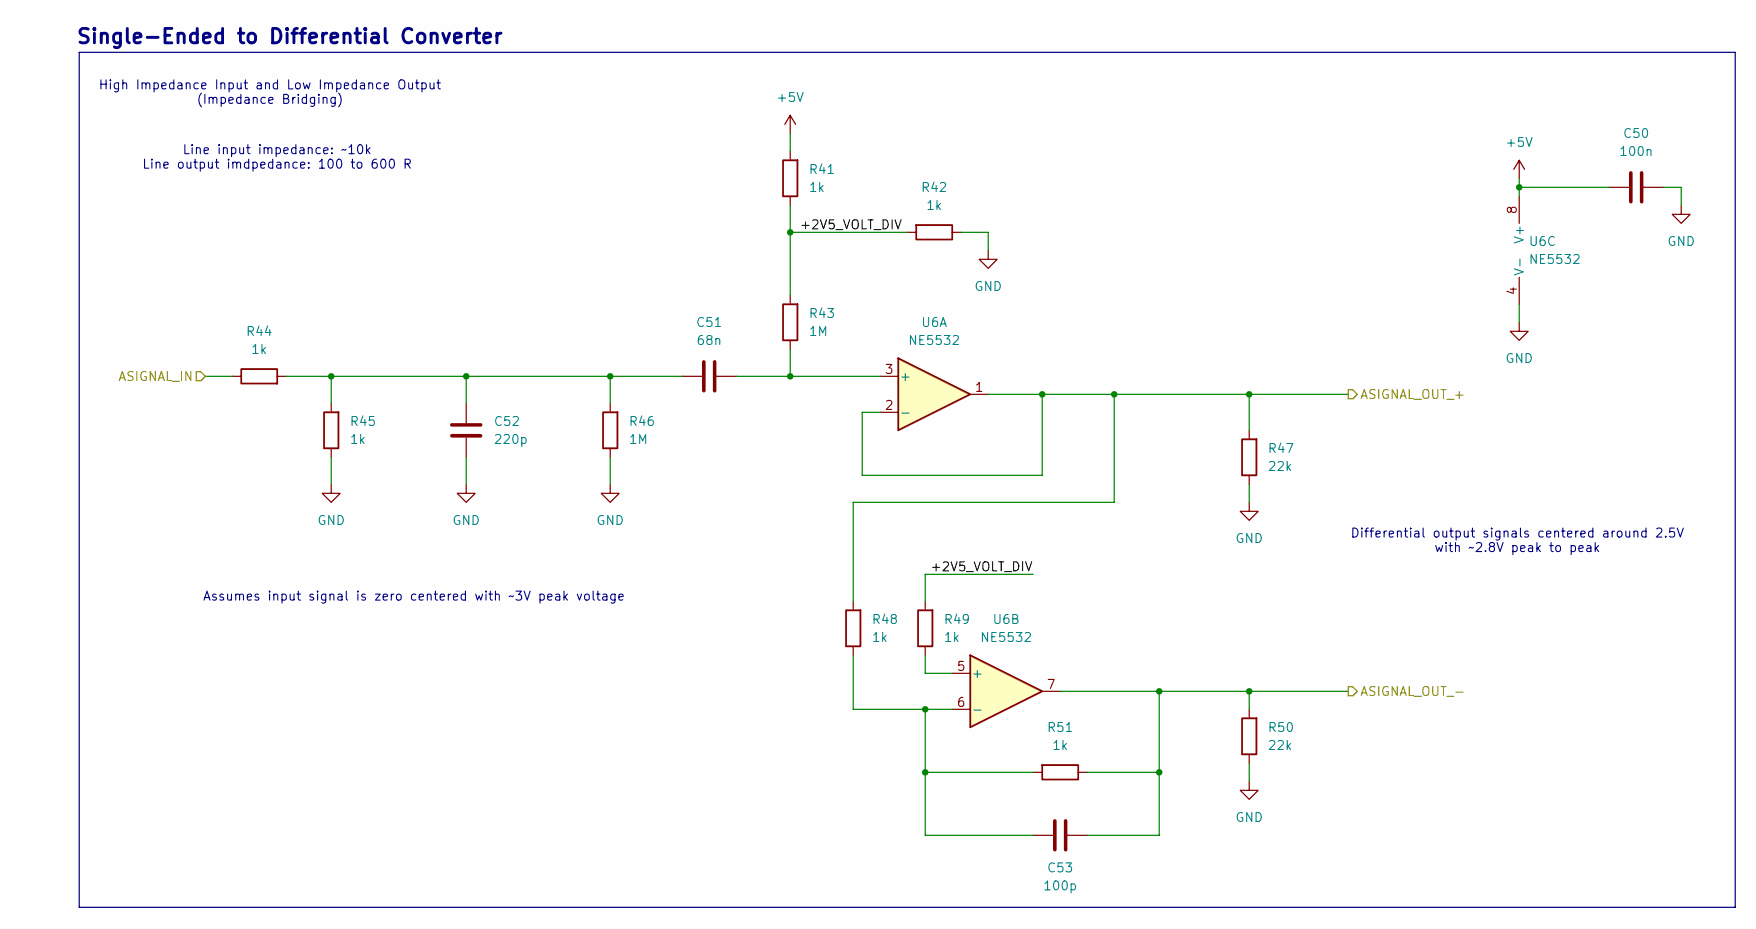
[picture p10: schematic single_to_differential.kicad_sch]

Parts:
C50: 100n; C_0805_2012Metric
C51: 68n; C_0805_2012Metric
C52: 220p; C_0805_2012Metric
C53: 100p; C_0805_2012Metric
R41, R42, R44, R45, R48, R49, R51: 1k; R_0805_2012Metric
R43, R46: 1M; R_0805_2012Metric
R47, R50: 22k; R_0805_2012Metric
U6: NE5532; SOIC-8_3.9x4.9mm_P1.27mm

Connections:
+5V: C50.1, R41.2, U6.8 (V+); also elsewhere on the board
/ASIGNAL_IN_R: R44.1; also elsewhere on the board
/ASIGNAL_IN_R+: R47.2, R48.2, U6.1, U6.2 (-); also elsewhere on the board
/ASIGNAL_IN_R-: C53.1, R50.2, R51.1, U6.7; also elsewhere on the board
/Single-Ended to Differential Converter Channel B/+2V5_VOLT_DIV: R41.1, R42.2, R43.2, R49.2
GND: C50.2, C52.2, R42.1, R45.1, R46.1, R47.1, R50.1, U6.4 (V-); also elsewhere on the board
unnamed: C51.1, C52.1, R44.2, R45.2, R46.2
unnamed: C51.2, R43.1, U6.3 (+)
unnamed: R49.1, U6.5 (+)
unnamed: C53.2, R48.1, R51.2, U6.6 (-)

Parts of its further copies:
C46: 100n; C_0805_2012Metric
C47: 68n; C_0805_2012Metric
C48: 220p; C_0805_2012Metric
C49: 100p; C_0805_2012Metric
R30, R31, R33, R34, R37, R38, R40: 1k; R_0805_2012Metric
R32, R35: 1M; R_0805_2012Metric
R36, R39: 22k; R_0805_2012Metric
U5: NE5532; SOIC-8_3.9x4.9mm_P1.27mm

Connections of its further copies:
+5V: C46.1, R30.2, U5.8 (V+); also elsewhere on the board
/ASIGNAL_IN_L: R33.1; also elsewhere on the board
/ASIGNAL_IN_L+: R36.2, R37.2, U5.1, U5.2 (-); also elsewhere on the board
/ASIGNAL_IN_L-: C49.1, R39.2, R40.1, U5.7; also elsewhere on the board
/Single-Ended to Differential Converter Channel A/+2V5_VOLT_DIV: R30.1, R31.2, R32.2, R38.2
GND: C46.2, C48.2, R31.1, R34.1, R35.1, R36.1, R39.1, U5.4 (V-); also elsewhere on the board
unnamed: C47.1, C48.1, R33.2, R34.2, R35.2
unnamed: C47.2, R32.1, U5.3 (+)
unnamed: R38.1, U5.5 (+)
unnamed: C49.2, R37.1, R40.2, U5.6 (-)

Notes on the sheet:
Assumes input signal is zero centered with ~3V peak voltage
Single-Ended to Differential Converter
High Impedance Input and Low Impedance Output (Impedance Bridging)
Differential output signals centered around 2.5V with ~2.8V peak to peak
Line input impedance: ~10k Line output imdpedance: 100 to 600 R

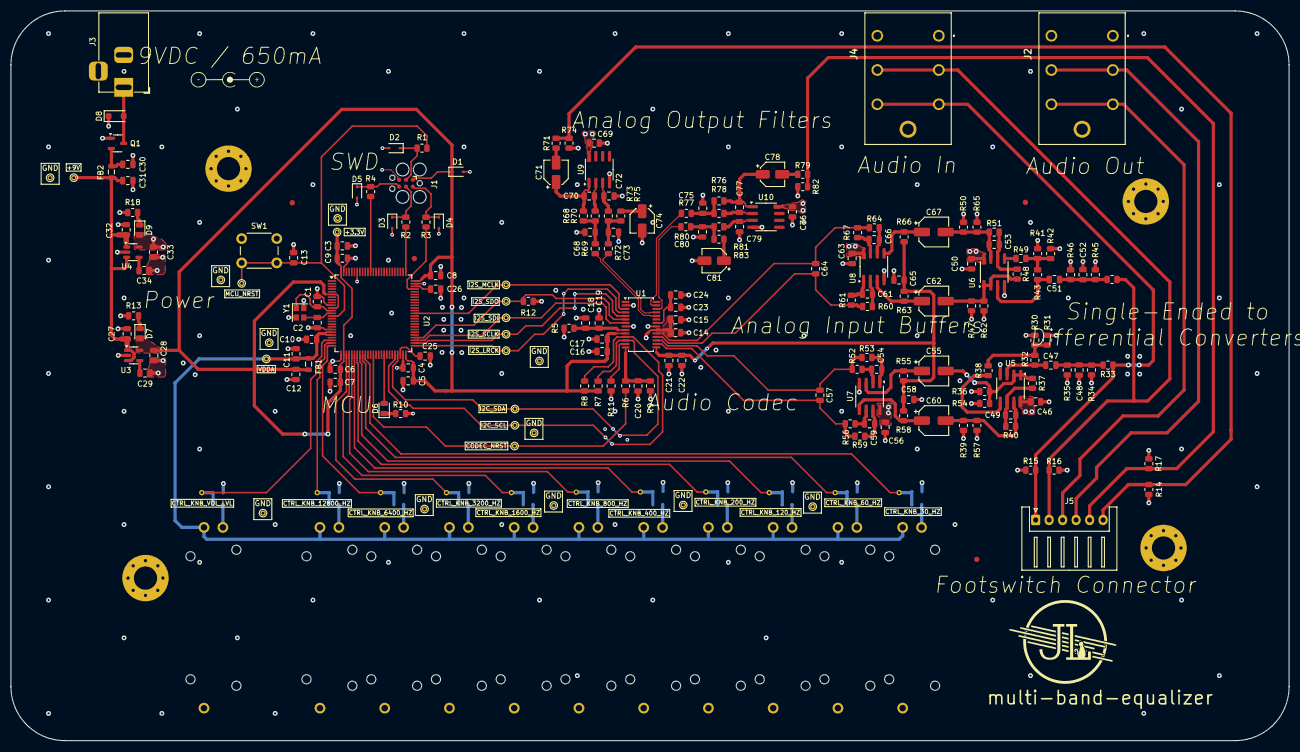
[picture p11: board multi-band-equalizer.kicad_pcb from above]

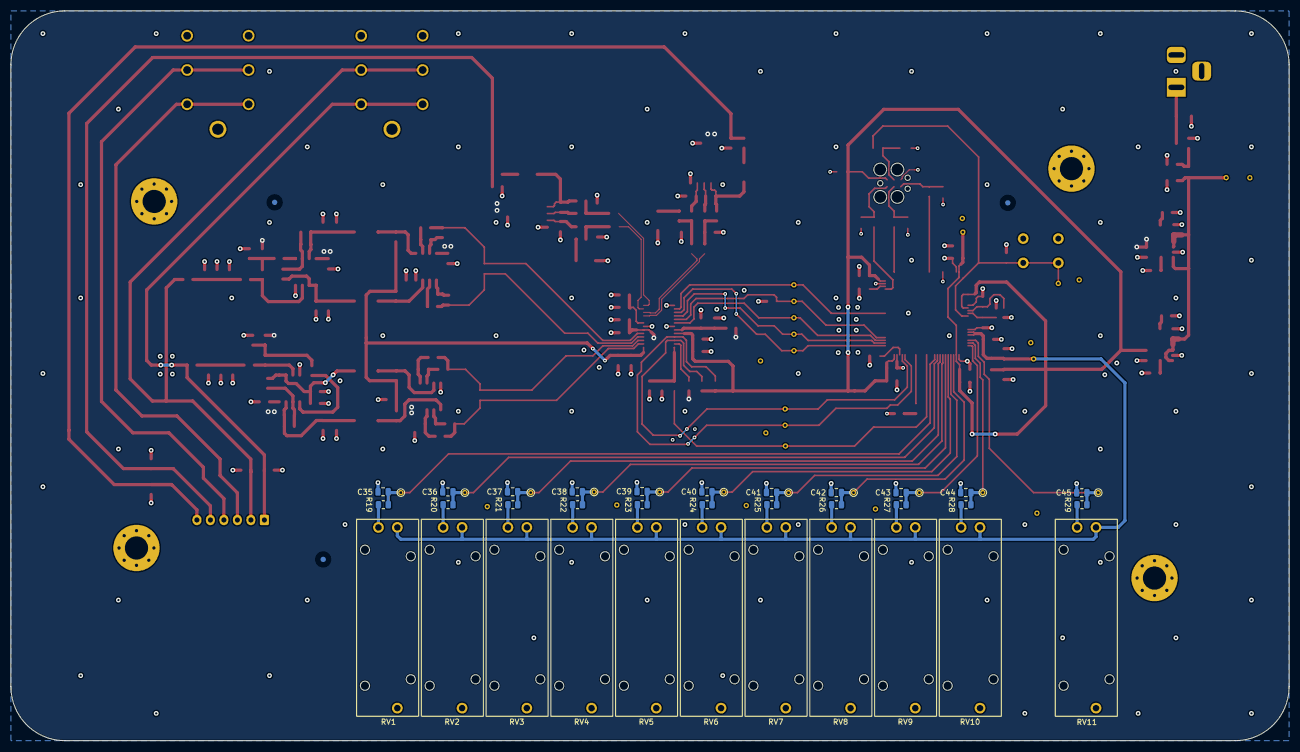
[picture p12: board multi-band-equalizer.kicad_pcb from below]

Board: 4 copper layers, 236.9 x 135.2 mm, 249 parts (47 on the bottom side), 114 nets.

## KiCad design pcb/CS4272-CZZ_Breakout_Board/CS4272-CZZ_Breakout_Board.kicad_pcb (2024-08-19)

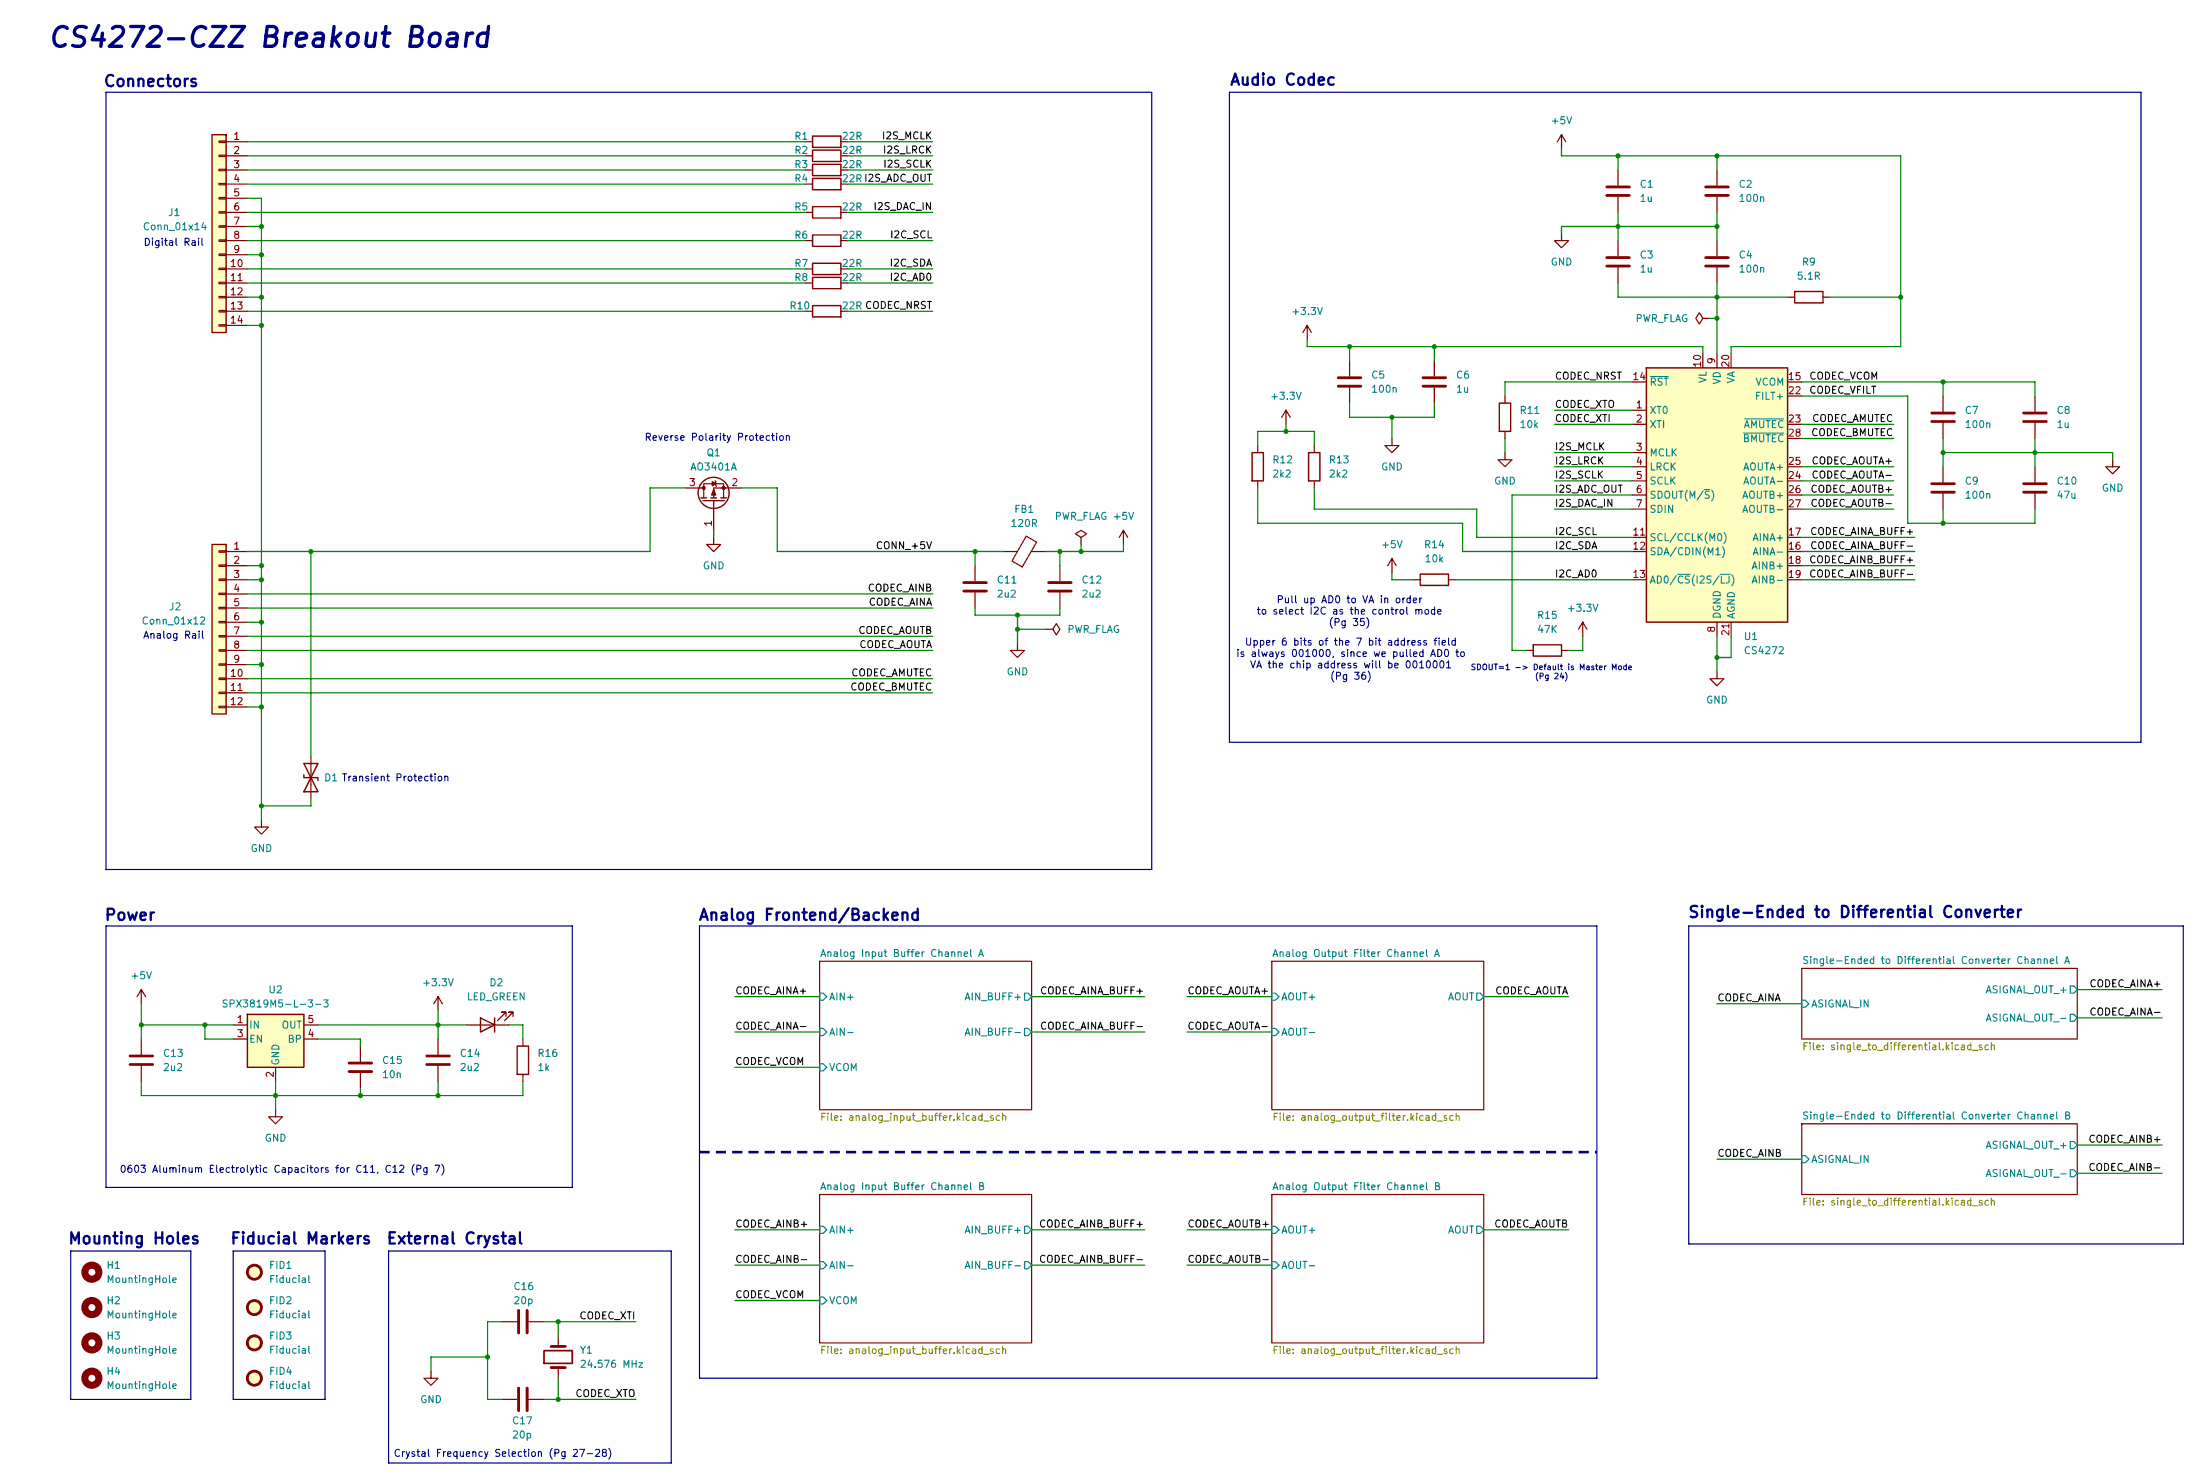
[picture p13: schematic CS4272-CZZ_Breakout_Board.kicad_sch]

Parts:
C1, C3, C6, C8: 1u; C_0805_2012Metric
C2, C4, C5, C7, C9: 100n; C_0805_2012Metric
C10: 47u; C_0805_2012Metric
C11, C12, C13, C14: 2u2; C_0805_2012Metric
C15: 10n; C_0805_2012Metric
C16, C17: 20p; C_0805_2012Metric
D1: D_TVS; D_SOD-323
D2: LED_GREEN; LED_0805_2012Metric
FB1: 120R; L_0805_2012Metric
FID1, FID2, FID3, FID4: Fiducial; Fiducial_1mm_Mask3mm
H1, H2, H3, H4: MountingHole; MountingHole_2.2mm_M2
J1: Conn_01x14; PinHeader_1x14_P2.54mm_Vertical
J2: Conn_01x12; PinHeader_1x12_P2.54mm_Vertical
Q1: AO3401A; SOT-23
R1, R2, R3, R4, R5, R6, R7, R8, R10: 22R; R_0805_2012Metric
R9: 5.1R; R_0805_2012Metric
R11, R14: 10k; R_0805_2012Metric
R12, R13: 2k2; R_0805_2012Metric
R15: 47K; R_0805_2012Metric
R16: 1k; R_0805_2012Metric
U1: CS4272; TSSOP-28_4.4x9.7mm_P0.65mm
U2: SPX3819M5-L-3-3; SOT-23-5
Y1: 24.576 MHz; Crystal_HC49-4H_Vertical

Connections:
+3.3V: C5.1, C6.1, C14.1, D2.2 (A), R12.1, R13.1, R15.1, U1.10 (VL), U2.5 (OUT)
+5V: C1.1, C2.1, C12.1, C13.1, FB1.2, R9.2, R14.1, U1.20 (VA), U2.1 (IN), U2.3 (EN); also elsewhere on the board
/CODEC_AINA: J2.5; also elsewhere on the board
/CODEC_AINA_BUFF+: U1.17 (AINA+); also elsewhere on the board
/CODEC_AINA_BUFF-: U1.16 (AINA-); also elsewhere on the board
/CODEC_AINB: J2.4; also elsewhere on the board
/CODEC_AINB_BUFF+: U1.18 (AINB+); also elsewhere on the board
/CODEC_AINB_BUFF-: U1.19 (AINB-); also elsewhere on the board
/CODEC_AMUTEC: J2.10, U1.23 (~AMUTEC)
/CODEC_AOUTA: J2.8; also elsewhere on the board
/CODEC_AOUTA+: U1.25 (AOUTA+); also elsewhere on the board
/CODEC_AOUTA-: U1.24 (AOUTA-); also elsewhere on the board
/CODEC_AOUTB: J2.7; also elsewhere on the board
/CODEC_AOUTB+: U1.26 (AOUTB+); also elsewhere on the board
/CODEC_AOUTB-: U1.27 (AOUTB-); also elsewhere on the board
/CODEC_BMUTEC: J2.11, U1.28 (~BMUTEC)
/CODEC_NRST: R10.2, R11.1, U1.14 (~RST)
/CODEC_VCOM: C7.1, C8.1, U1.15 (VCOM); also elsewhere on the board
/CODEC_VFILT: C9.2, C10.2, U1.22 (FILT+)
/CODEC_XTI: C16.1, U1.2 (XTI), Y1.2
/CODEC_XTO: C17.1, U1.1 (XT0), Y1.1
/CONN_+5V: C11.1, FB1.1, Q1.2 (S)
/I2C_AD0: R8.2, R14.2, U1.13 (AD0/~CS(I2S/~LJ))
/I2C_SCL: R6.2, R13.2, U1.11 (SCL/CCLK(M0))
/I2C_SDA: R7.2, R12.2, U1.12 (SDA/CDIN(M1))
/I2S_ADC_OUT: R4.2, R15.2, U1.6 (SDOUT(M/~S))
/I2S_DAC_IN: R5.2, U1.7 (SDIN)
/I2S_LRCK: R2.2, U1.4 (LRCK)
/I2S_MCLK: R1.2, U1.3 (MCLK)
/I2S_SCLK: R3.2, U1.5 (SCLK)
GND: C1.2, C2.2, C3.1, C4.1, C5.2, C6.2, C7.2, C8.2, C9.1, C10.1, C11.2, C12.2, C13.2, C14.2, C15.2, C16.2, C17.2, D1.1 (A1), J1.5, J1.7, J1.9, J1.12, J1.14, J2.2, J2.3, J2.6, J2.9, J2.12, Q1.1 (G), R11.2, R16.2, U1.8 (DGND), U1.21 (AGND), U2.2 (GND); also elsewhere on the board
unnamed: D1.2 (A2), J2.1, Q1.3 (D)
unnamed: D2.1 (K), R16.1
unnamed: J1.1, R1.1
unnamed: J1.2, R2.1
unnamed: J1.3, R3.1
unnamed: J1.4, R4.1
unnamed: J1.6, R5.1
unnamed: J1.8, R6.1
unnamed: J1.10, R7.1
unnamed: J1.11, R8.1
unnamed: J1.13, R10.1
unnamed: C3.2, C4.2, R9.1, U1.9 (VD)
unnamed: C15.1, U2.4 (BP)

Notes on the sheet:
Power
Crystal Frequency Selection (Pg 27-28)
CS4272-CZZ Breakout Board
Pull up AD0 to VA in order to select I2C as the control mode (Pg 35)
Digital Rail
Connectors
Reverse Polarity Protection
Mounting Holes
Analog Frontend/Backend
Upper 6 bits of the 7 bit address field is always 001000, since we pulled AD0 to VA the chip address will be 0010001 (Pg 36)
SDOUT=1 -> Default is Master Mode (Pg 24)
0603 Aluminum Electrolytic Capacitors for C11, C12 (Pg 7)
Transient Protection
Audio Codec
Analog Rail
External Crystal
Fiducial Markers
Single-Ended to Differential Converter

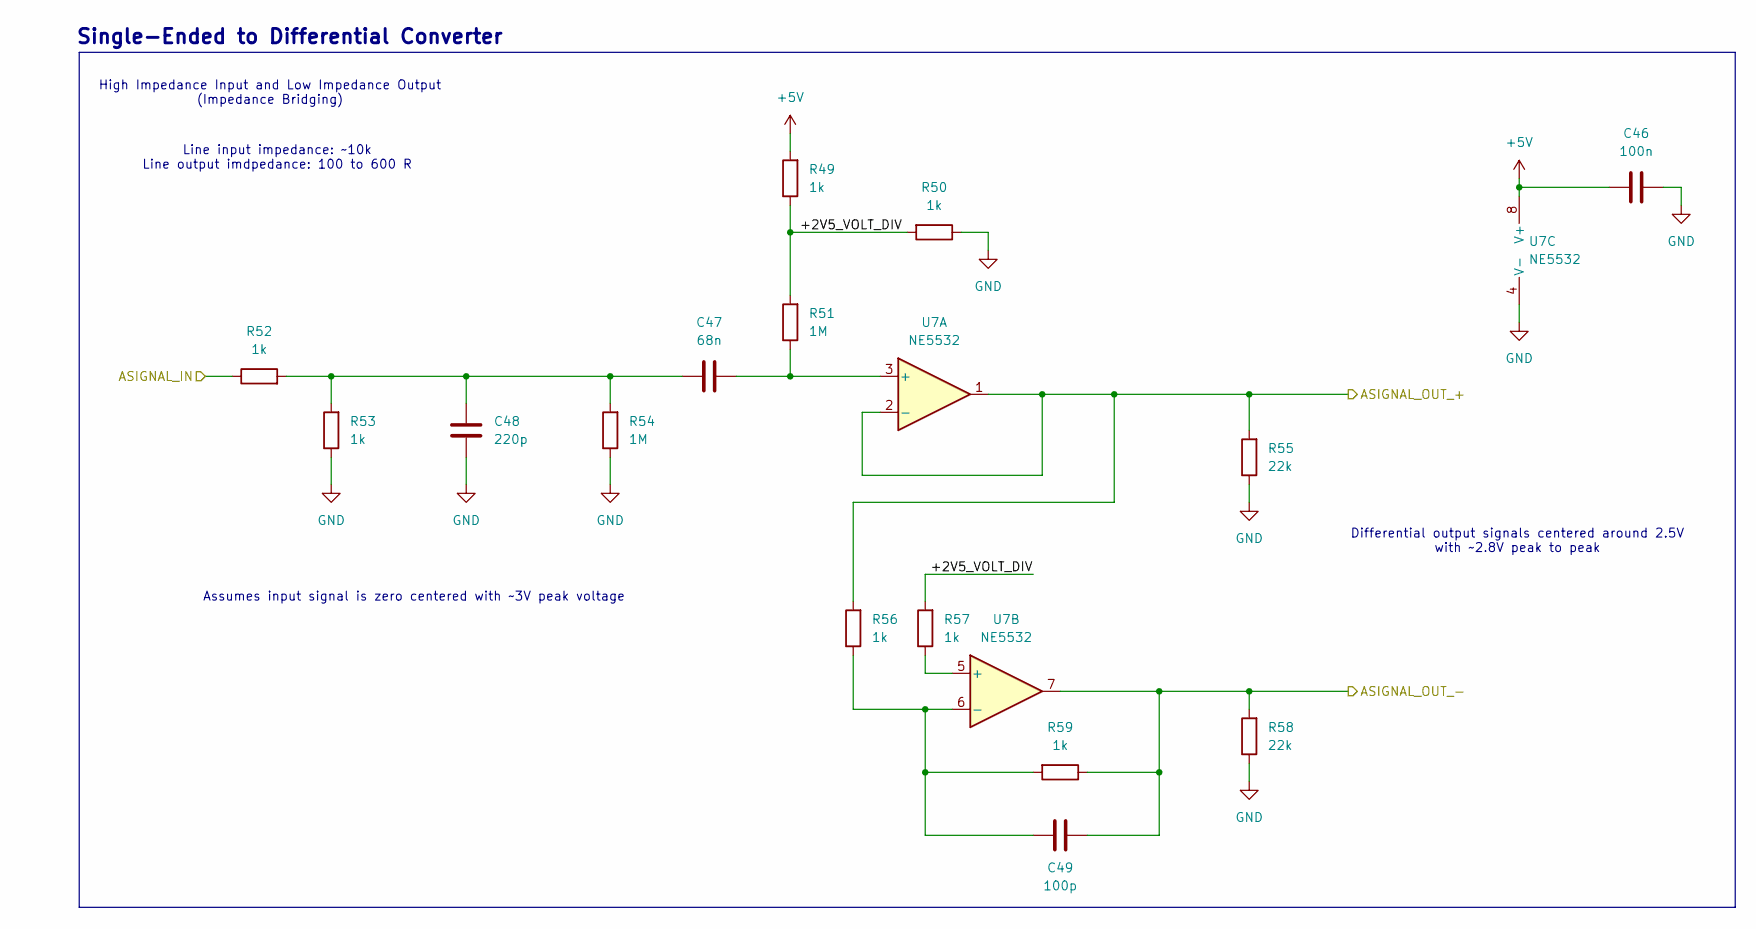
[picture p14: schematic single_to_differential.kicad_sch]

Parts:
C46: 100n; C_0805_2012Metric
C47: 68n; C_0805_2012Metric
C48: 220p; C_0805_2012Metric
C49: 100p; C_0805_2012Metric
R49, R50, R52, R53, R56, R57, R59: 1k; R_0805_2012Metric
R51, R54: 1M; R_0805_2012Metric
R55, R58: 22k; R_0805_2012Metric
U7: NE5532; SOIC-8_3.9x4.9mm_P1.27mm

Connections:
+5V: C46.1, R49.2, U7.8 (V+); also elsewhere on the board
/CODEC_AINA: R52.1; also elsewhere on the board
/CODEC_AINA+: R55.2, R56.2, U7.1, U7.2 (-); also elsewhere on the board
/CODEC_AINA-: C49.1, R58.2, R59.1, U7.7; also elsewhere on the board
/Single-Ended to Differential Converter Channel A/+2V5_VOLT_DIV: R49.1, R50.2, R51.2, R57.2
GND: C46.2, C48.2, R50.1, R53.1, R54.1, R55.1, R58.1, U7.4 (V-); also elsewhere on the board
unnamed: C47.1, C48.1, R52.2, R53.2, R54.2
unnamed: C47.2, R51.1, U7.3 (+)
unnamed: R57.1, U7.5 (+)
unnamed: C49.2, R56.1, R59.2, U7.6 (-)

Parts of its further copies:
C50: 100n; C_0805_2012Metric
C51: 68n; C_0805_2012Metric
C52: 220p; C_0805_2012Metric
C53: 100p; C_0805_2012Metric
R60, R61, R63, R64, R67, R68, R70: 1k; R_0805_2012Metric
R62, R65: 1M; R_0805_2012Metric
R66, R69: 22k; R_0805_2012Metric
U8: NE5532; SOIC-8_3.9x4.9mm_P1.27mm

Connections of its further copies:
+5V: C50.1, R60.2, U8.8 (V+); also elsewhere on the board
/CODEC_AINB: R63.1; also elsewhere on the board
/CODEC_AINB+: R66.2, R67.2, U8.1, U8.2 (-); also elsewhere on the board
/CODEC_AINB-: C53.1, R69.2, R70.1, U8.7; also elsewhere on the board
/Single-Ended to Differential Converter Channel B/+2V5_VOLT_DIV: R60.1, R61.2, R62.2, R68.2
GND: C50.2, C52.2, R61.1, R64.1, R65.1, R66.1, R69.1, U8.4 (V-); also elsewhere on the board
unnamed: C51.1, C52.1, R63.2, R64.2, R65.2
unnamed: C51.2, R62.1, U8.3 (+)
unnamed: R68.1, U8.5 (+)
unnamed: C53.2, R67.1, R70.2, U8.6 (-)

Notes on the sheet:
Assumes input signal is zero centered with ~3V peak voltage
Single-Ended to Differential Converter
High Impedance Input and Low Impedance Output (Impedance Bridging)
Differential output signals centered around 2.5V with ~2.8V peak to peak
Line input impedance: ~10k Line output imdpedance: 100 to 600 R

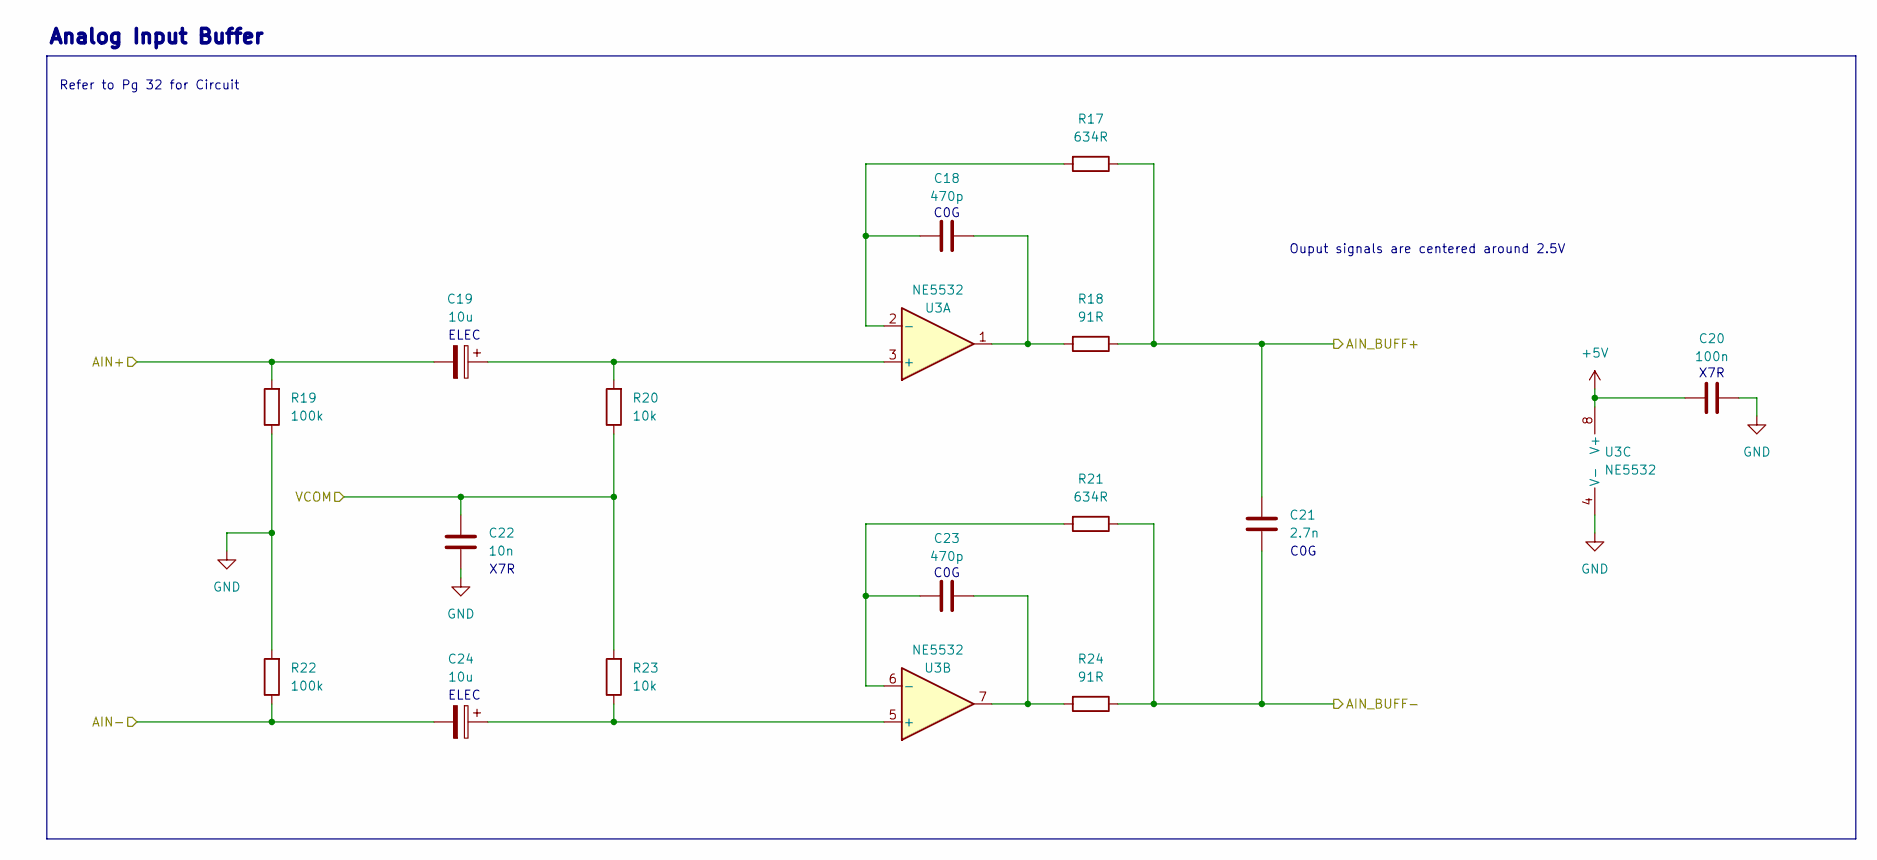
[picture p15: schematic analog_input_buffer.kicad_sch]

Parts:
C18, C23: 470p; C_0805_2012Metric
C19, C24: 10u; CP_Elec_5x5.4
C20: 100n; C_0805_2012Metric
C21: 2.7n; C_0805_2012Metric
C22: 10n; C_0805_2012Metric
R17, R21: 634R; R_0805_2012Metric
R18, R24: 91R; R_0805_2012Metric
R19, R22: 100k; R_0805_2012Metric
R20, R23: 10k; R_0805_2012Metric
U3: NE5532; SOIC-8_3.9x4.9mm_P1.27mm

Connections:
+5V: C20.1, U3.8 (V+); also elsewhere on the board
/CODEC_AINA+: C19.2, R19.2; also elsewhere on the board
/CODEC_AINA-: C24.2, R22.1; also elsewhere on the board
/CODEC_AINA_BUFF+: C21.2, R17.1, R18.1; also elsewhere on the board
/CODEC_AINA_BUFF-: C21.1, R21.1, R24.1; also elsewhere on the board
/CODEC_VCOM: C22.1, R20.1, R23.2; also elsewhere on the board
GND: C20.2, C22.2, R19.1, R22.2, U3.4 (V-); also elsewhere on the board
unnamed: C18.2, R18.2, U3.1
unnamed: C23.2, R24.2, U3.7
unnamed: C19.1, R20.2, U3.3 (+)
unnamed: C18.1, R17.2, U3.2 (-)
unnamed: C24.1, R23.1, U3.5 (+)
unnamed: C23.1, R21.2, U3.6 (-)

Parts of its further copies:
C32, C37: 470p; C_0805_2012Metric
C33, C38: 10u; CP_Elec_5x5.4
C34: 100n; C_0805_2012Metric
C35: 2.7n; C_0805_2012Metric
C36: 10n; C_0805_2012Metric
R33, R37: 634R; R_0805_2012Metric
R34, R40: 91R; R_0805_2012Metric
R35, R38: 100k; R_0805_2012Metric
R36, R39: 10k; R_0805_2012Metric
U5: NE5532; SOIC-8_3.9x4.9mm_P1.27mm

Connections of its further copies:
+5V: C34.1, U5.8 (V+); also elsewhere on the board
/CODEC_AINB+: C33.2, R35.2; also elsewhere on the board
/CODEC_AINB-: C38.2, R38.1; also elsewhere on the board
/CODEC_AINB_BUFF+: C35.2, R33.1, R34.1; also elsewhere on the board
/CODEC_AINB_BUFF-: C35.1, R37.1, R40.1; also elsewhere on the board
/CODEC_VCOM: C36.1, R36.1, R39.2; also elsewhere on the board
GND: C34.2, C36.2, R35.1, R38.2, U5.4 (V-); also elsewhere on the board
unnamed: C32.2, R34.2, U5.1
unnamed: C37.2, R40.2, U5.7
unnamed: C33.1, R36.2, U5.3 (+)
unnamed: C32.1, R33.2, U5.2 (-)
unnamed: C38.1, R39.1, U5.5 (+)
unnamed: C37.1, R37.2, U5.6 (-)

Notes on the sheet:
C0G
Analog Input Buffer
X7R
Refer to Pg 32 for Circuit
Ouput signals are centered around 2.5V
ELEC


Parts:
C39: 2.2n; C_0805_2012Metric
C40: 100n; C_0805_2012Metric
C41: 470p; C_0805_2012Metric
C42, C45: 22u; CP_Elec_4x5.4
C43: 1.5n; C_0805_2012Metric
C44: 6.8n; C_0805_2012Metric
R41: 4.99k; R_0805_2012Metric
R42: 4.42k; R_0805_2012Metric
R43: 2.32k; R_0805_2012Metric
R44: 1.3K; R_0805_2012Metric
R45: 1.33k; R_0805_2012Metric
R46: 715R; R_0805_2012Metric
R47: 47k; R_0805_2012Metric
R48: 1.5k; R_0805_2012Metric
U6: NE5532; SOIC-8_3.9x4.9mm_P1.27mm

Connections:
+5V: C40.1, U6.8 (V+); also elsewhere on the board
/CODEC_AOUTB: R44.2, R47.2; also elsewhere on the board
/CODEC_AOUTB+: R45.1; also elsewhere on the board
/CODEC_AOUTB-: R42.1; also elsewhere on the board
GND: C39.1, C40.2, C43.2, C44.1, C45.2, R47.1, U6.4 (V-); also elsewhere on the board
unnamed: C39.2, R41.1, R42.2, R43.1
unnamed: C41.2, C42.1, R41.2, U6.1
unnamed: C42.2, R44.1
unnamed: C44.2, R45.2, R46.1, R48.1
unnamed: C45.1, R48.2
unnamed: C43.1, R46.2, U6.3 (+)
unnamed: C41.1, R43.2, U6.2 (-)

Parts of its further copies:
C25: 2.2n; C_0805_2012Metric
C26: 100n; C_0805_2012Metric
C27: 470p; C_0805_2012Metric
C28, C31: 22u; CP_Elec_4x5.4
C29: 1.5n; C_0805_2012Metric
C30: 6.8n; C_0805_2012Metric
R25: 4.99k; R_0805_2012Metric
R26: 4.42k; R_0805_2012Metric
R27: 2.32k; R_0805_2012Metric
R28: 1.3K; R_0805_2012Metric
R29: 1.33k; R_0805_2012Metric
R30: 715R; R_0805_2012Metric
R31: 47k; R_0805_2012Metric
R32: 1.5k; R_0805_2012Metric
U4: NE5532; SOIC-8_3.9x4.9mm_P1.27mm

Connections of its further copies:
+5V: C26.1, U4.8 (V+); also elsewhere on the board
/CODEC_AOUTA: R28.2, R31.2; also elsewhere on the board
/CODEC_AOUTA+: R29.1; also elsewhere on the board
/CODEC_AOUTA-: R26.1; also elsewhere on the board
GND: C25.1, C26.2, C29.2, C30.1, C31.2, R31.1, U4.4 (V-); also elsewhere on the board
unnamed: C25.2, R25.1, R26.2, R27.1
unnamed: C27.2, C28.1, R25.2, U4.1
unnamed: C28.2, R28.1
unnamed: C30.2, R29.2, R30.1, R32.1
unnamed: C31.1, R32.2
unnamed: C29.1, R30.2, U4.3 (+)
unnamed: C27.1, R27.2, U4.2 (-)

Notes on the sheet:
C0G
Refer to Pg 33 for Circuit
X7R
2-Pole Butterworth Low Pass Filter
Second Op Amp not used
Ouput signals are centered around 2.5V
ELEC
Analog Output Filter


Board: 2 copper layers, 141.1 x 78.5 mm, 146 parts (0 on the bottom side), 84 nets.

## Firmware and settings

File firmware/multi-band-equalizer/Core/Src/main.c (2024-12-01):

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
/* Includes ------------------------------------------------------------------*/
#include "main.h"

/* USER CODE BEGIN Includes */
#include <stdio.h>
#include <string.h>

#include "CS4272.h"
#include "EMAFilter.h"
#include "PeakingFilter.h"
/* USER CODE END Includes */

/* USER CODE BEGIN PD */
#define AUDIO_DATA_BUFFER_SIZE  128
#define AUDIO_SAMPLE_RATE_HZ 	48000.0f

#define NUM_CTRL_KNOBS 		 11 // 10 Frequency Bands, 1 Volume Level
#define NUM_FREQ_BANDS 		 10
#define CTRL_KNOBS_DEADBAND  0.05f
#define CTRL_KNOBS_EMA_ALPHA 0.85f // Alpha factor for EMA Low Pass Filter (Lower alpha -> Lower cutoff frequency)

#define MAX_OUTPUT_VOLUME_SCALE 2.0f
#define MAX_FILTER_GAIN_SCALE 4.0f // Must be positive
#define MIN_FILTER_GAIN_SCALE 0.25f // Must be positive

#define ADC_RAW_NORMALIZATION_FACTOR 65535 // 2^16 - 1
#define INT32_TO_FLOAT 				 4.6566128752e-10f // 1 / (2^(32-1) - 1)
#define FLOAT_TO_INT32 				 2.147483647e9f // 2^(32-1) - 1
/* USER CODE END PD */

ADC_HandleTypeDef hadc1;
DMA_HandleTypeDef hdma_adc1;

I2C_HandleTypeDef hi2c2;

I2S_HandleTypeDef hi2s2;
DMA_HandleTypeDef hdma_spi2_rx;
DMA_HandleTypeDef hdma_spi2_tx;

TIM_HandleTypeDef htim1;

/* USER CODE BEGIN PV */
// CS4272 Codec
CS4272 codec;

// CMSIS IIR Filters for Stereo Channel
IIR_Direct_Form_1 left_iir_filter;
IIR_Direct_Form_1 right_iir_filter;

// Struct to hold our filter parameters that can be changed by the control knobs
PeakingFilterParameters peaking_filters_params[NUM_FREQ_BANDS];

// EMA Low Pass Filters for the Control Knobs
EMAFilter ema_filters[NUM_CTRL_KNOBS];

// Pre-defined fixed center frequencies for our peaking filters
static const float peaking_filter_center_freqs[NUM_FREQ_BANDS] = {
		30.0f,
		60.0f,
		120.0f,
		200.0f,
		400.0f,
		800.0f,
		1600.0f,
		3200.0f,
		6400.0f,
		12800.0f
};

// Pre-defined fixed bandwidths for our peaking filters
static const float peaking_filter_bandwidths[NUM_FREQ_BANDS] = {
		5.0f,
		10.0f,
		20.0f,
		40.0f,
		100.0f,
		145.0f,
		240.0f,
		500.0f,
		1200.0f,
		6000.0f
};

// Ping Pong buffers for our codec's ADC and DAC
volatile int32_t audio_adc_buff[AUDIO_DATA_BUFFER_SIZE] = {0};
volatile int32_t audio_dac_buff[AUDIO_DATA_BUFFER_SIZE] = {0};
// Access pointers to our audio data buffers
static volatile int32_t *audio_in_buff_ptr = &audio_adc_buff[0];
static volatile int32_t *audio_out_buff_ptr = &audio_dac_buff[0];
// Stereo buffers for IIR filters
static float left_input_buffer[AUDIO_DATA_BUFFER_SIZE/4] = {0};
static float left_output_buffer[AUDIO_DATA_BUFFER_SIZE/4] = {0};
static float right_input_buffer[AUDIO_DATA_BUFFER_SIZE/4] = {0};
static float right_output_buffer[AUDIO_DATA_BUFFER_SIZE/4] = {0};
// Flag to indicate that our current in buffer has filled up and is ready to be switched with the out buffer
volatile uint8_t audio_buff_samples_rdy = 0;

// Buffer to hold our raw sampled control knob signals
volatile uint16_t ctrl_knobs_settings_raw[NUM_CTRL_KNOBS] = {0};
// Buffer to hold our control knob signals normalized to [0.0, 1.0] (First 7 are frequency bands, Last is Volume Level)
volatile float 	  ctrl_knobs_settings[NUM_CTRL_KNOBS] = {0};
// Buffer to hold memory of the control knob samples for low pass filtering purposes/deadband calculations
volatile float    prev_ctrl_knobs_settings[NUM_CTRL_KNOBS] = {0};

volatile uint8_t  ctrl_knobs_adc_samples_rdy = 0;
// Flag to indicate control knobs are being changed
volatile uint8_t  ctrl_knobs_adc_lock = 0;
// Lock to make sure we don't change ctrl_knobs_settings in the middle of processing
volatile uint8_t  ctrl_knobs_audio_proc_lock = 0;

// Keeps track of the audio output level (Left and Right channels are equally leveled)
volatile float output_volume_level = 1.0f;
/* USER CODE END PV */

void SystemClock_Config(void);
static void MX_GPIO_Init(void);
static void MX_DMA_Init(void);
static void MX_ADC1_Init(void);
static void MX_I2S2_Init(void);
static void MX_I2C2_Init(void);
static void MX_TIM1_Init(void);
/* USER CODE BEGIN 0 */
// Callback for our control knobs
void HAL_ADC_ConvCpltCallback(ADC_HandleTypeDef *hadc)
{
	if (!ctrl_knobs_adc_lock)
	{
		for (size_t i=0; i<NUM_CTRL_KNOBS; ++i)
		{
			// Convert raw ADC samples from the control knobs to floats and normalize to [0.0, 1.0]
			ctrl_knobs_settings[i] = (float) (ctrl_knobs_settings_raw[i]) / ADC_RAW_NORMALIZATION_FACTOR;
		}
		ctrl_knobs_adc_samples_rdy = 1;
	}
}

// Converts processed control knob samples into filter parameters
void processControlKnobs()
{
	// Set our lock to prevent the ADC from updating the ctrl_knobs_settings during this function call
	ctrl_knobs_adc_lock = 1;

	if (!ctrl_knobs_audio_proc_lock)
	{
		for (size_t i=0; i<NUM_CTRL_KNOBS; ++i)
		{
			// Low Pass Filter the control knob signals
			ctrl_knobs_settings[i] = EMAFilter_Update(&ema_filters[i], ctrl_knobs_settings[i]);

			if (i != NUM_CTRL_KNOBS-1)
			{
				if (fabs(ctrl_knobs_settings[i]-prev_ctrl_knobs_settings[i]) > CTRL_KNOBS_DEADBAND)
				{
					// If we are past the deadband then update our filter_params

					// Center frequencies are fixed and go from [100, 6400] Hz
					if (peaking_filters_params[i].center_freq_hz != peaking_filter_center_freqs[i])
					{
						peaking_filters_params[i].center_freq_hz = peaking_filter_center_freqs[i];
					}

					// Bandwidths are fixed and go from [5, 6000] Hz
					if (peaking_filters_params[i].bandwidth_hz != peaking_filter_bandwidths[i])
					{
						peaking_filters_params[i].bandwidth_hz = peaking_filter_bandwidths[i];
					}

					// Update the filter gain
					peaking_filters_params[i].gain_linear = ((MAX_FILTER_GAIN_SCALE - MIN_FILTER_GAIN_SCALE) * ctrl_knobs_settings[i]) + MIN_FILTER_GAIN_SCALE;
				}
			}
			else
			{
				// Update the output_volume_level
				output_volume_level = MAX_OUTPUT_VOLUME_SCALE * ctrl_knobs_settings[i];
			}

			// Update the prev_ctrl_knobs_settings
			prev_ctrl_knobs_settings[i] = ctrl_knobs_settings[i];
		}
		// Update our IIR filters with our new parameters
		PeakingFilter_Set_Coefficients_CMSIS(&left_iir_filter, peaking_filters_params, NUM_FREQ_BANDS);
		PeakingFilter_Set_Coefficients_CMSIS(&right_iir_filter, peaking_filters_params, NUM_FREQ_BANDS);
	}

	// Reset ctrl_knobs_adc_lock
	ctrl_knobs_adc_lock = 0;
	// Reset ctrl_knobs_adc_samples_rdy to indicate we need a new batch of ctrl_knobs_settings samples from the ADC
	ctrl_knobs_adc_samples_rdy = 0;
}



// Callbacks for ping ponging I2S audio TX and RX buffers
void HAL_I2SEx_TxRxHalfCpltCallback(I2S_HandleTypeDef *hi2s)
{
	audio_in_buff_ptr = &audio_adc_buff[0];
	audio_out_buff_ptr = &audio_dac_buff[0];

	audio_buff_samples_rdy = 1;
}

void HAL_I2SEx_TxRxCpltCallback(I2S_HandleTypeDef *hi2s)
{
	audio_in_buff_ptr = &audio_adc_buff[AUDIO_DATA_BUFFER_SIZE/2];
	audio_out_buff_ptr = &audio_dac_buff[AUDIO_DATA_BUFFER_SIZE/2];

	audio_buff_samples_rdy = 1;
}

// Function that processes the audio data held in the buffers
void processAudioData()
{
	// Set our control knob lock to prevent any changes to the control settings during this function call
	ctrl_knobs_audio_proc_lock = 1;


	for (size_t i=0; i<(AUDIO_DATA_BUFFER_SIZE/4); ++i)
	{
		// Fill in our input buffers and convert int32_t to floats for processing
		left_input_buffer[i] = INT32_TO_FLOAT * ((float) audio_in_buff_ptr[2*i]);
		right_input_buffer[i] = INT32_TO_FLOAT * ((float) audio_in_buff_ptr[(2*i)+1]);
	}

	PeakingFilter_Update_CMSIS(&left_iir_filter, left_input_buffer, left_output_buffer, AUDIO_DATA_BUFFER_SIZE/4);
	PeakingFilter_Update_CMSIS(&right_iir_filter, right_input_buffer, right_output_buffer, AUDIO_DATA_BUFFER_SIZE/4);

	const float scaling_factor = FLOAT_TO_INT32 * output_volume_level;
	for (size_t i=0; i<(AUDIO_DATA_BUFFER_SIZE/4); ++i)
	{
		// Fill in our output buffers
		audio_out_buff_ptr[2*i] = scaling_factor * left_output_buffer[i];
		audio_out_buff_ptr[(2*i)+1] = scaling_factor * right_output_buffer[i];
	}

	// Reset our control knob lock since we completed processing
	ctrl_knobs_audio_proc_lock = 0;
	// Reset audio_buff_samples_rdy to indicate we need a new batch of audio samples from I2S
	audio_buff_samples_rdy = 0;
}
/* USER CODE END 0 */

/**
  * @brief  The application entry point.
  * @retval int
  */
int main(void)
{

  /* MCU Configuration--------------------------------------------------------*/

  /* Reset of all peripherals, Initializes the Flash interface and the Systick. */
  HAL_Init();

  /* Configure the system clock */
  SystemClock_Config();

  /* Initialize all configured peripherals */
  MX_GPIO_Init();
  MX_DMA_Init();
  MX_ADC1_Init();
  MX_I2S2_Init();
  MX_I2C2_Init();
  MX_TIM1_Init();
  /* USER CODE BEGIN 2 */
  // Calibrate ADC 1
  HAL_ADCEx_Calibration_Start(&hadc1, ADC_CALIB_OFFSET, ADC_SINGLE_ENDED);
  // Start ADC 1 with DMA to read in our control knobs
  HAL_ADC_Start_DMA(&hadc1, (uint32_t *) ctrl_knobs_settings_raw, NUM_CTRL_KNOBS);
  // Start timer 1 for clocking ADC 1
  HAL_TIM_Base_Start(&htim1);

  // Initialize our codec
  uint8_t status = CS4272_Init(&codec, &hi2c2);
  if (status != 0)
  {
	  // Error
	  HAL_GPIO_WritePin(LED_STATUS_RED_GPIO_Port, LED_STATUS_RED_Pin, GPIO_PIN_SET);
  }
  // Initialize our IIR Peaking Filters
  PeakingFilter_Init_CMSIS(&left_iir_filter, AUDIO_SAMPLE_RATE_HZ);
  PeakingFilter_Init_CMSIS(&right_iir_filter, AUDIO_SAMPLE_RATE_HZ);
  // Initialize our EMA Low Pass Filters
  EMAFilters_Init(ema_filters, (size_t) NUM_CTRL_KNOBS, CTRL_KNOBS_EMA_ALPHA);

  // Initialize our I2S data stream
  HAL_I2SEx_TransmitReceive_DMA(&hi2s2, (uint16_t *) audio_dac_buff, (uint16_t *) audio_adc_buff, AUDIO_DATA_BUFFER_SIZE);
  /* USER CODE END 2 */

  /* Infinite loop */
  /* USER CODE BEGIN WHILE */
  while (1)
  {
    /* USER CODE END WHILE */

    /* USER CODE BEGIN 3 */
	  if (audio_buff_samples_rdy)
	  {
		  // Buffers are initialized with audio data, we can process the data now
		  processAudioData();
	  }

	  if (ctrl_knobs_adc_samples_rdy)
	  {
		  // Buffers are initialized with control knob data, we can process the data now
		  processControlKnobs();
	  }

  }
  /* USER CODE END 3 */
}

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


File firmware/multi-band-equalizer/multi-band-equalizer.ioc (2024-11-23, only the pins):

Mcu.UserName=STM32H7B0VBTx
PA1.GPIO_Label=CTRL_KNB_VOL_LVL
PA1.Signal=ADC1_INP17
PA13.Signal=DEBUG_JTMS-SWDIO
PA14.Signal=DEBUG_JTCK-SWCLK
PA2.GPIO_Label=CTRL_KNB_12800_HZ
PA2.Signal=ADCx_INP14
PA3.GPIO_Label=CTRL_KNB_6400_HZ
PA3.Signal=ADC1_INP15
PA4.GPIO_Label=CTRL_KNB_3200_HZ
PA4.Signal=ADCx_INP18
PA5.GPIO_Label=CTRL_KNB_1600_HZ
PA5.Signal=ADCx_INP19
PA6.GPIO_Label=CTRL_KNB_800_HZ
PA6.Signal=ADCx_INP3
PA7.GPIO_Label=CTRL_KNB_400_HZ
PA7.Signal=ADCx_INP7
PB0.GPIO_Label=CTRL_KNB_60_HZ
PB0.Signal=ADCx_INP9
PB1.GPIO_Label=CTRL_KNB_30_HZ
PB1.Signal=ADCx_INP5
PB10.Signal=I2C2_SCL
PB11.Signal=I2C2_SDA
PB12.GPIO_Label=I2S2_LRCK
PB12.Signal=I2S2_WS
PB13.GPIO_Label=I2S2_SCLK
PB13.Signal=I2S2_CK
PB14.Signal=I2S2_SDI
PB15.Signal=I2S2_SDO
PB3.Signal=DEBUG_JTDO-SWO
PC4.GPIO_Label=CTRL_KNB_200_HZ
PC4.Signal=ADCx_INP4
PC5.GPIO_Label=CTRL_KNB_120_HZ
PC5.Signal=ADCx_INP8
PC6.GPIO_Label=I2S2_MCLK
PC6.Signal=I2S2_MCK
PE12.GPIO_Label=LED_STATUS_RED
PE12.Signal=GPIO_Output
PE8.GPIO_Label=CODEC_NRST
PE8.Signal=GPIO_Output
PH0-OSC_IN.Signal=RCC_OSC_IN
PH1-OSC_OUT.Signal=RCC_OSC_OUT

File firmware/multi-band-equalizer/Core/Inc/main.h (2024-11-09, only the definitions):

#define CTRL_KNB_VOL_LVL_Pin GPIO_PIN_1
#define CTRL_KNB_VOL_LVL_GPIO_Port GPIOA
#define CTRL_KNB_12800_HZ_Pin GPIO_PIN_2
#define CTRL_KNB_12800_HZ_GPIO_Port GPIOA
#define CTRL_KNB_6400_HZ_Pin GPIO_PIN_3
#define CTRL_KNB_6400_HZ_GPIO_Port GPIOA
#define CTRL_KNB_3200_HZ_Pin GPIO_PIN_4
#define CTRL_KNB_3200_HZ_GPIO_Port GPIOA
#define CTRL_KNB_1600_HZ_Pin GPIO_PIN_5
#define CTRL_KNB_1600_HZ_GPIO_Port GPIOA
#define CTRL_KNB_800_HZ_Pin GPIO_PIN_6
#define CTRL_KNB_800_HZ_GPIO_Port GPIOA
#define CTRL_KNB_400_HZ_Pin GPIO_PIN_7
#define CTRL_KNB_400_HZ_GPIO_Port GPIOA
#define CTRL_KNB_200_HZ_Pin GPIO_PIN_4
#define CTRL_KNB_200_HZ_GPIO_Port GPIOC
#define CTRL_KNB_120_HZ_Pin GPIO_PIN_5
#define CTRL_KNB_120_HZ_GPIO_Port GPIOC
#define CTRL_KNB_60_HZ_Pin GPIO_PIN_0
#define CTRL_KNB_60_HZ_GPIO_Port GPIOB
#define CTRL_KNB_30_HZ_Pin GPIO_PIN_1
#define CTRL_KNB_30_HZ_GPIO_Port GPIOB
#define CODEC_NRST_Pin GPIO_PIN_8
#define CODEC_NRST_GPIO_Port GPIOE
#define LED_STATUS_RED_Pin GPIO_PIN_12
#define LED_STATUS_RED_GPIO_Port GPIOE
#define I2S2_LRCK_Pin GPIO_PIN_12
#define I2S2_LRCK_GPIO_Port GPIOB
#define I2S2_SCLK_Pin GPIO_PIN_13
#define I2S2_SCLK_GPIO_Port GPIOB
#define I2S2_MCLK_Pin GPIO_PIN_6
#define I2S2_MCLK_GPIO_Port GPIOC

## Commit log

2024-08-09 PCB update
    [CS4272-CZZ_Breakout_Board-B_Cu.gbr, CS4272-CZZ_Breakout_Board-B_Mask.gbr, CS4272-CZZ_Breakout_Board-B_Paste.gbr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]
2024-08-19 Update Ver 1
    [CS4272-CZZ_Breakout_Board-B_Cu.gbl, CS4272-CZZ_Breakout_Board-B_Mask.gbr, CS4272-CZZ_Breakout_Board-B_Mask.gbs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]
2024-08-26 firmware update
    [multi-band-equalizer Debug.cfg]
2024-09-21 Added multi-band-equalizer PCB
    [analog_input_buffer.kicad_sch, analog_output_filter.kicad_sch, multi-band-equalizer.kicad_pcb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]
2024-09-22 Fixed peaking filter calculation
2024-09-23 Renamed firmware project
    [multi-band-equalizer Debug.cfg]
2024-09-27 pcb updates
    [analog_input_buffer.kicad_sch, analog_output_filter.kicad_sch, multi-band-equalizer.kicad_sch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]
2024-10-05 Fix i2s and filter calculations
    [CS4272-CZZ_Breakout_Board.ioc, main.c]
2024-10-14 Update schematic
    [multi-band-equalizer.kicad_pcb, multi-band-equalizer.kicad_sch]
2024-10-20 sliding potentiometers
    [analog_input_buffer.kicad_sch, analog_input_buffer.sch, analog_output_filter.kicad_sch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]
2024-10-24 Added custom pcb libraries
2024-10-25 Update pcb
    [analog_input_buffer.kicad_sch, analog_output_filter.kicad_sch, multi-band-equalizer.kicad_pcb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]
2024-10-27 Updated pcb and script
    [analog_input_buffer.kicad_sch, analog_output_filter.kicad_sch, multi-band-equalizer.kicad_pcb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]
2024-11-09 stitching vias
    [multi-band-equalizer.kicad_pcb]
2024-11-15 new gerbers
    [multi-band-equalizer-B_Cu.gbr, multi-band-equalizer-B_Mask.gbr, multi-band-equalizer-B_Paste.gbr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]
2024-11-16 resistor value
    [multi-band-equalizer.kicad_pcb, multi-band-equalizer.kicad_sch]
2024-11-28 add chassis drawing
    [multi-band-equalizer.kicad_pcb]

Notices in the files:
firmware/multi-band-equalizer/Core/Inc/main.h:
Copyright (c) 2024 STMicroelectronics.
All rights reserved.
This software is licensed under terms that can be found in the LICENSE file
